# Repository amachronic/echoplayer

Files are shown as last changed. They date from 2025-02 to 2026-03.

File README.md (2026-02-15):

# Echo: Open Hardware Music Player

Echo is an open hardware platform for music players. The goal of
the project is to produce a high quality music player, based on
and designed with free software. It's primarily designed to run
[Rockbox](https://www.rockbox.org), a free music player firmware
with support for many codecs, and a wide array of features.

The PCB is designed with [KiCAD 9.0](https://www.kicad.org/),
and there is an unfinished 3D-printable case designed with
[build123d](https://github.com/gumyr/build123d).

All designs are available under the CERN-OHL-S v2 license.

The current version of the Echo player is called the Echo R1.
In the future, there could be new player models if there are
significant changes to the features or form factor, but old
models will always be supported.

## Echo R1

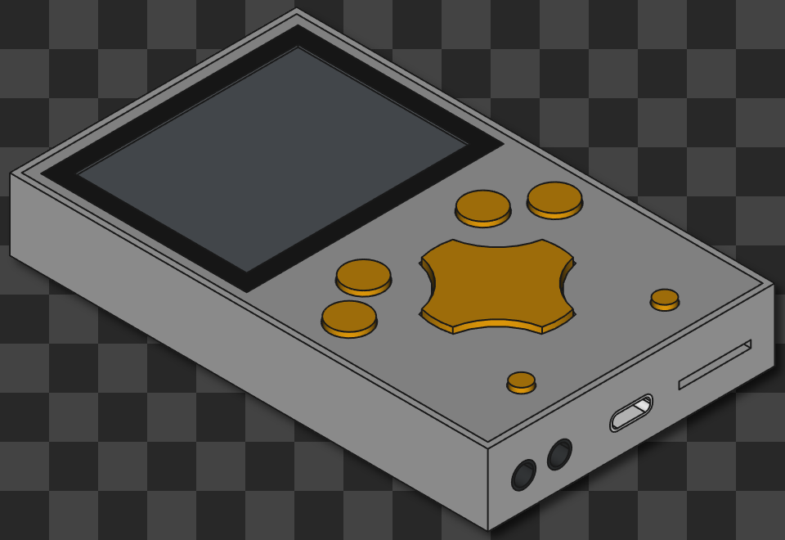
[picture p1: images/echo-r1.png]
3D render of Echo R1 case


- Size: 60x100x15mm (approx)
- Weight: TBD

The R1 has a 4-way D-pad and 6 multi-function buttons on the
faceplate, which can be used to quickly navigate your music
library and control playback. There are dedicated volume and
power buttons (not pictured), and a sliding hold switch near
the power button, which locks the buttons against accidental
presses when the player is in your pocket or bag.

There are two 3.5mm jacks, one for headphones, and one true
line-out port. The headphone jack supports recording from an
in-line microphone and playback control by an in-line remote.
Both jacks can be used simultaneously.

The removable memory card slot allows up to 2 TiB of storage
for your music and files. The USB-C port is used for charging
and file transfer, and supports high-speed USB 2.0.

The battery socket accepts the widely available BL-5C battery,
and the battery can easily be replaced without special tools
when it starts to wear out.

### Hardware specifications

| Component | Description |
| --- | --- |
| CPU | STM32H743 @ 480 MHz |
| Memory | 32 MiB SDRAM @ 120 MHz |
| Audio | TLV320AIC3104, up to 96 KHz, 0.707 V RMS  |
| Display | 18-bit, 320x240, 2.3 inch LCD |
| Storage | Expandable external memory card slot |
| USB | USB 2.0 @ 480 Mbps (High-speed) |
| Headphone out | Yes (3.5mm jack) |
| Line out | Yes (3.5mm jack) |
| Microphone | Can use wired headphone mic |
| RTC | Yes, with wake-up alarm function |
| Battery | Replaceable BL-5C battery (~1000 mAH) |

### Status

There are two versions of the R1 in the repo, the Rev1 and Rev2.

Rev1 is complete from an electrical standpoint but has a poorly
thought out mechanical design. A very early Rockbox port exists
but it is far from usable.

Rev2 is unfinished and focused mostly on solving the mechanical
issues with Rev1 properly. It is a near total redesign from an
electrical perspective, and uses a STM32H7R3 series CPU which
was selected mainly to simplify routing.

### Known issues (R1-Rev1 only)

- Reference designators in the schematics don't make much sense,
  there are gaps in the numbering and samed-valued components are
  not in contiguous ranges.
- Mounting screws are placed haphazardly and only two of them
  proved to be usable.
- The placement of the LCD and LCD connector is very awkward and
  makes it hard to diassemble the machine non-destructively.
- The lack of mounting holes also makes it difficult to connect
  front and back halves of the case securely.

## License

Unless otherwise noted, all files in this repository, including
this README, are available under the terms of the CERN-OHL-S
version 2 license, which should be found in the file `COPYING.txt`
alongside this README; or at <https://ohwr.org/cern_ohl_s_v2.txt>.

## Credits

Copyright (C) 2024-2025 Aidan MacDonald

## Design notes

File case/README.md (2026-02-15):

# Echo R1 Case

The Echo R1 case is designed with [build123d](https://github.com/gumyr/build123d),
a Python-based parametric BREP CAD package using the OpenCASCADE
geometry kernel. The case can be exported to STEP or STL files for
3D printing or to edit in other CAD applications.

## Installation

CAD models are produced by running the `echoplayer-case` script.
This needs to be installed first; the recommended way is to set
up a Python virtual environment (venv) and perform an editable
install, which allows you to modify and run the script in place.

This can be done from the shell / command line like this:

```
python3 -m venv .venv
source .venv/bin/activate
pip install -U pip
pip install -e .
```

## Exporting

To export STLs, run:

```
echoplayer-case --r1-rev1 --export out
```

You can also output STEP (or GLTF) files with the `--export-format` option:

```
echoplayer-case --r1-rev1 --export out --export-format stp
```

STEP is recommended if you want to make changes in another BREP
CAD package. STLs are meshes and only suitable for 3D printing.

The `--export DIR` option will write one file per unique part
to the output directory `DIR`. Some parts, like buttons, will
require multiple copies produced. At some point this will be
properly documented in BOM data for the player, but for now
you need to figure it out from looking at the render.

## Visualizing

If making edits to the code, you probably want to see what you are
doing to the model. There is built-in support for
[ocp_vscode](https://github.com/bernhard-42/vscode-ocp-cad-viewer),
which can be run either from VSCode or as a standalone server that
is accessed by a browser.

To start the standalone server:

```
python3 -m ocp_vscode
```

Navigate to `http://localhost:3939/viewer` in a browser and then
display the model with:

```
echoplayer-case --r1-rev1 --ocp-vscode
```

Passing the `--show-datums` option will include datum points and
planes in the visualization.

## Development

If you are going to be making any major changes to the Python code,
you should install development dependencies and run checks with `tox`.
Run the following command in a venv:

```
pip install -e .[dev]
```

Usage of `tox` is very simple:

```
tox r -e mypy   # type check
tox r -e ruff   # lint
tox r -e test   # test build of the case
tox p           # run all in parallel
```

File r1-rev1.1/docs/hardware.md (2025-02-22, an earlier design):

# Hardware notes

Usage notes for the hardware -- for further information consult the
KiCAD schematic and `pin_assign.ods` file.

## Fast/slow charging mode

To enable 450 mA charging, `~charging_enable` must be pulled to ground,
otherwise the charge is limited to 100 mA. This isn't strictly USB 2.0
compliant but provides an option to draw less current when plugging into
weak USB hosts (eg. a phone).

## Power-on circuit management

The power-on circuit controls the main 3.3V regulator enable pin and
thus is used to power on the STM32 MCU. There are 4 power-on signals
which are active high and OR'd through diodes:

* CPU power (`cpu_power_on` pin)
* RTC wakeup (`rtc_wakeup` pin)
* Power button
* VBUS input

In the normal case, the user will press and hold the power button to
power on the machine. Once the STM32 boots, the bootloader continues
to monitor the button, and if it stays pressed for a certain duration
it will assert the `cpu_power_on` request to keep the CPU powered on
once the power button is released.

The RTC wakeup case is much like the power button case, except that
the bootloader detects the RTC wakeup and boots the firmware with
no user input.

Providing USB power ensures the STM32 is powered even if there is no
software on it. This allows it to be flashed over SWD or USB-DFU.

To shut off the CPU, the firmware should drive `cpu_power_on` low and
wait for some time. It should then trigger a software reset in order
to re-enter the bootloader. If the bootloader is re-entered in this way
it should go into an idle mode to manage battery charging, etc, which
should appear as if the device is 'off' from the user perspective and
respond as expected to the power button / RTC alarm. If USB power is
lost, the bootloader should attempt to shut off the system again.

## Audio codec and jacks

There are two 3.5mm audio jacks driven by the TLV320AIC3104 codec:

- Headphone jack -- direct-coupled (capless) headphone amp output
- Line-out jack -- AC-coupled line output

Both jacks have insert detection and can be driven simultaneously.
The headphone jack supports recording from an inline microphone and
headset button detection following the Android 3.5mm accessory spec.
Both jacks are designed for the CTIA pinout and support 4-pin CTIA
and 3-pin plugs; 4-pin OMTP plugs may not work correctly.

## USB-DFU mode and SWD

The STM32 can be programmed using USB DFU mode by holding SELECT
while inserting a USB cable. This will enter the ST bootloader and
it should appear as a USB-DFU device.

The 6-pin SWD connector can be used to debug and program the STM32
using OpenOCD. This requires an SWD adapter such as the STLINK-V3SET.
The default configuration files for the STM32H743 and your adapter
should be sufficient, no special configuration is required.

Note that software breakpoints in GDB will not work correctly on
Cortex-M7 when the I-cache is enabled, due a bug in OpenOCD. To
work around this, you can use GDB's `hbreak` command to force the
use of hardware breakpoints or you can disable the I-cache.

## Board stackup and ordering information

The board is designed for JLCPCB's 6-layer JLC06101H-3313 stackup.
Trace widths have been selected to get 50-ohm impedance on single
ended signal traces and 90-ohm differential impedance on USB. Via
impedance wasn't taken into account as it shouldn't matter except
at much higher speeds.

For QFN exposed pads the grounding vias in the KiCAD footprint are
smaller than the min. size used on the rest of the board. It should
be fine to enlarge them to the standard via size if required but
JLCPCB seemed to accept them as-is.

| Parameter | Value |
| --- | --- |
| Layers | 6 |
| Thickness | 1.6mm |
| Material | FR-4 TG155 |
| Outer copper weight  | 1 oz |
| Inner copper weight  | 0.5 oz |
| Impedance controlled | Yes |
| Stackup | JLC06101H-3313 |
| Via covering | Epoxy filled & capped |
| Via pad/hole size | 0.45mm/0.3mm |

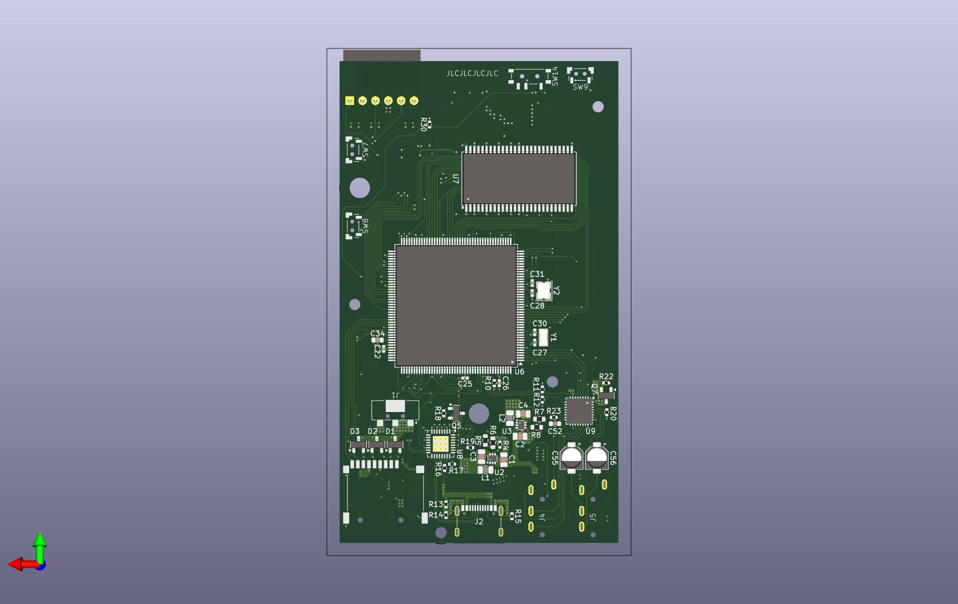
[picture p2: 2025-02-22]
images/echo-r1-back.jpg

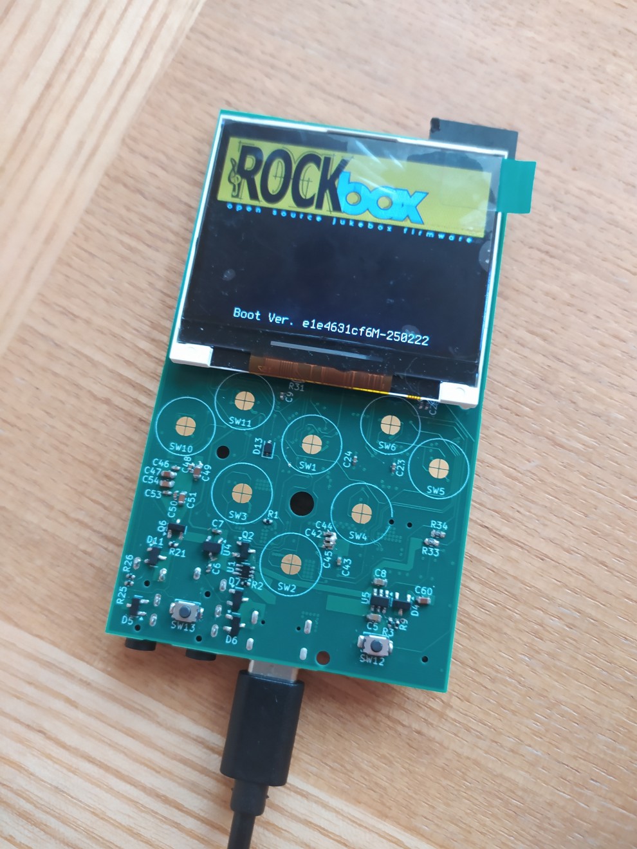
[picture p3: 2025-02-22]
images/echo-r1-rockbox.jpg

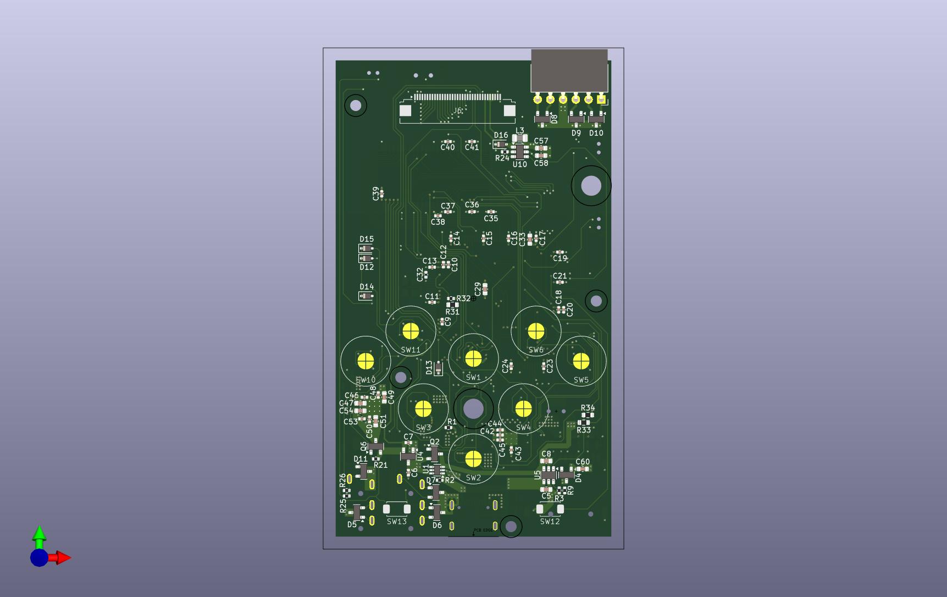
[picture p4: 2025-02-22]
images/echo-r1-front.jpg

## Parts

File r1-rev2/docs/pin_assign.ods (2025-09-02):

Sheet: README
PinAssign usage: | GPIO FUNCTION can be edited to mark a pin used as a GPIO, or give a name for an alternate function pin; use ‘-’ if the pin is not used/not named
 | PKGPIN and NAME are defined from the MCU datasheet – don’t edit these
 | ALT FUNCTION is populated automatically, don’t edit it
 | USED is populated automatically, it contains an ‘o’ if the pin is assigned to a GPIO or alternate function, ‘-’ if the pin is free
FunctionAssign usage: | Put an ‘x’ in the PIN NAME column if the alternate function is not used
 | Put the name of the GPIO (eg. PA3) in the PIN NAME column if the alternate function is assigned to that GPIO
 | Leave PIN NAME blank if undecided
 | FUNCTION is defined from the MCU datasheet – do not edit it
 | PKGPIN is populated automatically, don’t edit it
FunctionPinMux usage: | Used to view pins available for alternate functions, not used for editing. Use PinAssign/FunctionAssign to assign GPIOs or alternate functions.
_Data sheet: | contains a reverse mapping of pin name → pkgpin indices
 | also marks pins that are fixed function on the MCU so that those are always marked as ‘used’ on the PinAssign sheet

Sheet: PinAssign
PKGPIN | NAME | USED | ALT FUNCTION | GPIO FUNCTION | UnusedPinMark | x
A1 | VSS | o | - | - | UsedPinMark | o
A2 | PB8 | o | I2C1_SCL | codec_ctl.scl | NoPkgPinText | -
A3 | PB6 | o | USART1_TX | uart_tx
A4 | PB5 | - | - | -
A5 | PD7 | o | SDMMC2_CMD | sdmmc_int.cmd
A6 | BOOT0 | o | - | -
A7 | PM11 | o | OTG_FS_DP | -
A8 | PM9 | - | - | -
A9 | PM6 | o | OTG_HS_DP | -
A10 | VDD33USB | o | - | -
A11 | VDD50USB | o | - | -
A12 | VSS | o | - | -
B1 | VBAT | o | - | -
B2 | PC13 | o | RTC_OUT1 | rtc_wakeup
B3 | PE1 | - | - | -
B4 | PE0 | - | - | -
B5 | PB3 | o | SDMMC2_D2 | sdmmc_int.d2
B6 | PD5 | o | FMC_NCE | lcd.cs
B7 | PM12 | o | OTG_FS_DM | -
B8 | PM8 | o | OTG_HS_VBUS | -
B9 | PM5 | o | OTG_HS_DM | -
B10 | PM2 | - | - | -
B11 | PM3 | - | - | -
B12 | PD4 | - | - | -
C1 | PC14-OSC32_IN | o | OSC32_IN | -
C2 | PC15-OSC32_OUT | o | OSC32_OUT | -
C3 | PB9 | o | I2C1_SDA | codec_ctl.sda
C4 | PE2 | o | SAI1_MCLK_A | codec.mclk
C5 | PB4 | o | SDMMC2_D3 | sdmmc_int.d3
C6 | PD6 | o | SDMMC2_CK | sdmmc_int.clk
C7 | PM14 | o | OTG_FS_VBUS | -
C8 | DVDD | o | - | -
C9 | VSS | o | - | -
C10 | PM1 | - | - | -
C11 | PD2 | o | SDMMC1_CMD | sdmmc_ext.cmd
C12 | PC12 | o | SDMMC1_CK | sdmmc_ext.clk
D1 | PE5 | o | SAI1_SCK_A | codec.bclk
D2 | VSS | o | - | -
D3 | PE3 | o | SAI1_SD_B | codec.drec
D4 | PB7 | o | USART1_RX | uart_rx
D5 | VSS | o | - | -
D6 | VDD | o | - | -
D7 | VSS | o | - | -
D8 | VSSUSB | o | - | -
D9 | VDD | o | - | -
D10 | PD3 | o | FMC_NWAIT | -
D11 | PC10 | o | SDMMC1_D2 | sdmmc_ext.d2
D12 | PA15 | - | - | -
E1 | VSSSMPS | o | - | -
E2 | PE6 | o | SAI1_SD_A | codec.dplay
E3 | PE4 | o | SAI1_FS_A | codec.wclk
E4 | VDD | o | - | -
E5 | VCAP4 | o | - | -
E6 | PM13 | - | - | -
E7 | VSS | o | - | -
E8 | PM0 | - | - | -
E9 | PC11 | o | SDMMC1_D3 | sdmmc_ext.d3
E10 | PA14 | o | JTCK-SWCLK | -
E11 | PA12 | o | FMC_D0 | lcd.d0
E12 | PA13 | o | JTMS-SWDIO | -
F1 | VLXSMPS | o | - | -
F2 | VDDSMPS | o | - | -
F3 | VFBSMPS | o | - | -
F4 | NRST | o | - | -
F5 | VSS | o | - | -
F6 | VDDLDO | o | - | -
F7 | VDDLDO | o | - | -
F8 | VCAP3 | o | - | -
F9 | VDD | o | - | -
F10 | PA8 | o | FMC_D4 | lcd.d4
F11 | PA10 | o | FMC_D2 | lcd.d2
F12 | PA11 | o | FMC_D1 | lcd.d1
G1 | VSS | o | - | -
G2 | PH0-OSC_IN | o | OSC_IN | -
G3 | PC0 | - | - | -
G4 | VDD | o | - | -
G5 | PC1 | - | - | -
G6 | VDDLDO | o | - | -
G7 | VDDLDO | o | - | -
G8 | VSS | o | - | -
G9 | PC7 | - | - | -
G10 | PC9 | o | SDMMC1_D1 | sdmmc_ext.d1
G11 | PC8 | o | SDMMC1_D0 | sdmmc_ext.d0
G12 | PA9 | o | FMC_D3 | lcd.d3
H1 | PH1-OSC_OUT | o | OSC_OUT | -
H2 | PC3 | o | ADC12_INN12 | hp_micbutton-
H3 | VSSA | o | - | -
H4 | VSS | o | - | -
H5 | VREFM | o | - | -
H6 | VCAP1 | o | - | -
H7 | VSS | o | - | -
H8 | VCAP2 | o | - | -
H9 | PB14 | o | SDMMC2_D0 | sdmmc_int.d0
H10 | PB12 | - | - | -
H11 | PD14 | o | LPTIM2_CH1 | cpu_power_on
H12 | PC6 | - | - | -
J1 | PC2 | o | ADC12_INP12 | hp_micbutton+
J2 | PA1 | o | FMC_D6 | lcd.d6
J3 | VDDA | o | - | -
J4 | PA5 | - | - | -
J5 | VDD | o | - | -
J6 | PO1 | - | - | -
J7 | PO0 | o | XSPIM_P1_NCS1 | xspi.cs
J8 | PD8 | - | - | -
J9 | VDD | o | - | -
J10 | PB10 | - | - | -
J11 | PB13 | - | - | -
J12 | PB15 | o | SDMMC2_D1 | sdmmc_int.d1
K1 | PA0 | o | FMC_D7 | lcd.d7
K2 | PA3 | - | - | -
K3 | VREFP | o | - | -
K4 | PA7 | o | ADC12_INP7 | adc_vbat
K5 | VDDXSPI1 | o | - | -
K6 | VSS | o | - | -
K7 | VDDXSPI1 | o | - | -
K8 | VSS | o | - | -
K9 | VDDXSPI1 | o | - | -
K10 | VSS | o | - | -
K11 | PD12 | - | - | -
K12 | PB11 | - | - | -
L1 | PA2 | o | FMC_D5 | lcd.d5
L2 | PA4 | - | - | -
L3 | PC4 | o | FMC_A19 | lcd.dcx
L4 | PB0 | - | - | -
L5 | PB2 | o | FMC_NWE | lcd.wrx
L6 | PP2 | o | XSPIM_P1_IO2 | xspi.d2
L7 | PO5 | o | XSPIM_P1_NCLK | xspi.clk-
L8 | PP0 | o | XSPIM_P1_IO0 | xspi.d0
L9 | PO2 | o | XSPIM_P1_DQS0 | xspi.dqs0
L10 | PP1 | o | XSPIM_P1_IO1 | xspi.d1
L11 | PD11 | - | - | -
L12 | PD13 | o | LPTIM1_CH1 | backlight_pwm
M1 | VSS | o | - | -
M2 | PA6 | - | - | -
M3 | PC5 | o | ADC12_INP8 | adc_vbus
M4 | PB1 | o | FMC_NOE | lcd.rdx
M5 | PP4 | o | XSPIM_P1_IO4 | xspi.d4
M6 | PP3 | o | XSPIM_P1_IO3 | xspi.d3
M7 | PO4 | o | XSPIM_P1_CLK | xspi.clk+
M8 | PP5 | o | XSPIM_P1_IO5 | xspi.d5
M9 | PP6 | o | XSPIM_P1_IO6 | xspi.d6
M10 | PP7 | o | XSPIM_P1_IO7 | xspi.d7
M11 | PD10 | - | - | -
M12 | VSS | o | - | -
 | TOTAL PINS USED | 115
 | TOTAL PINS FREE | 29

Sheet: FunctionAssign
PKGPIN | FUNCTION | PIN NAME
L8 | XSPIM_P1_IO0 | PP0
L10 | XSPIM_P1_IO1 | PP1
L6 | XSPIM_P1_IO2 | PP2
M6 | XSPIM_P1_IO3 | PP3
M5 | XSPIM_P1_IO4 | PP4
M8 | XSPIM_P1_IO5 | PP5
M9 | XSPIM_P1_IO6 | PP6
M10 | XSPIM_P1_IO7 | PP7
L9 | XSPIM_P1_DQS0 | PO2
M7 | XSPIM_P1_CLK | PO4
L7 | XSPIM_P1_NCLK | PO5
J7 | XSPIM_P1_NCS1 | PO0
- | FMC_A0 | x
- | FMC_A1 | x
- | FMC_A2 | x
- | FMC_A3 | x
- | FMC_A4 | x
- | FMC_A5 | x
- | FMC_A6 | x
- | FMC_A7 | x
- | FMC_A16 | x
- | FMC_A17 | x
- | FMC_A18 | x
L3 | FMC_A19 | PC4
- | FMC_A20 | x
- | FMC_A21 | x
E11 | FMC_D0 | PA12
F12 | FMC_D1 | PA11
F11 | FMC_D2 | PA10
G12 | FMC_D3 | PA9
F10 | FMC_D4 | PA8
L1 | FMC_D5 | PA2
J2 | FMC_D6 | PA1
K1 | FMC_D7 | PA0
- | FMC_D8 | x
- | FMC_D9 | x
- | FMC_D10 | x
- | FMC_D11 | x
- | FMC_D12 | x
- | FMC_D13 | x
- | FMC_D14 | x
- | FMC_D15 | x
M4 | FMC_NOE | PB1
L5 | FMC_NWE | PB2
D10 | FMC_NWAIT | PD3
B6 | FMC_NCE | PD5
- | FMC_NE1 | x
C12 | SDMMC1_CK | PC12
C11 | SDMMC1_CMD | PD2
G11 | SDMMC1_D0 | PC8
G10 | SDMMC1_D1 | PC9
D11 | SDMMC1_D2 | PC10
E9 | SDMMC1_D3 | PC11
C6 | SDMMC2_CK | PD6
A5 | SDMMC2_CMD | PD7
H9 | SDMMC2_D0 | PB14
J12 | SDMMC2_D1 | PB15
B5 | SDMMC2_D2 | PB3
C5 | SDMMC2_D3 | PB4
B9 | OTG_HS_DM | PM5
A9 | OTG_HS_DP | PM6
- | OTG_HS_ID | x
- | OTG_HS_SOF | x
B8 | OTG_HS_VBUS | PM8
A7 | OTG_FS_DP | PM11
B7 | OTG_FS_DM | PM12
C7 | OTG_FS_VBUS | PM14
E3 | SAI1_FS_A | PE4
- | SAI1_FS_B | x
C4 | SAI1_MCLK_A | PE2
- | SAI1_MCLK_B | x
D1 | SAI1_SCK_A | PE5
- | SAI1_SCK_B | x
E2 | SAI1_SD_A | PE6
D3 | SAI1_SD_B | PE3
- | SAI2_FS_A | x
- | SAI2_FS_B | x
- | SAI2_MCLK_A | x
- | SAI2_MCLK_B | x
- | SAI2_SCK_A | x
- | SAI2_SCK_B | x
- | SAI2_SD_A | x
- | SAI2_SD_B | x
A2 | I2C1_SCL | PB8
C3 | I2C1_SDA | PB9
- | I2C2_SCL | x
- | I2C2_SDA | x
- | I2C3_SCL | x
- | I2C3_SDA | x
L12 | LPTIM1_CH1 | PD13
- | LPTIM1_CH2 | x
H11 | LPTIM2_CH1 | PD14
- | LPTIM2_CH2 | x
- | LPTIM3_CH1 | x
- | LPTIM3_CH2 | x
K4 | ADC12_INP7 | PA7
M3 | ADC12_INP8 | PC5
J1 | ADC12_INP12 | PC2
H2 | ADC12_INN12 | PC3
B2 | RTC_OUT1 | PC13
A3 | USART1_TX | PB6
D4 | USART1_RX | PB7
E10 | JTCK-SWCLK | PA14
E12 | JTMS-SWDIO | PA13
C1 | OSC32_IN | PC14-OSC32_IN
C2 | OSC32_OUT | PC15-OSC32_OUT
G2 | OSC_IN | PH0-OSC_IN
H1 | OSC_OUT | PH1-OSC_OUT

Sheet: FunctionPinMux
FUNCTION | PINS
XSPIM_P1_IO0 | PP0
XSPIM_P1_IO1 | PP1
XSPIM_P1_IO2 | PP2
XSPIM_P1_IO3 | PP3
XSPIM_P1_IO4 | PP4
XSPIM_P1_IO5 | PP5
XSPIM_P1_IO6 | PP6
XSPIM_P1_IO7 | PP7
XSPIM_P1_DQS0 | PO2
XSPIM_P1_CLK | PO4
XSPIM_P1_NCLK | PO5
XSPIM_P1_NCS1 | PO0
FMC_A0 | PC1
FMC_A1 | PC2
FMC_A2 | PC3
FMC_A3 | PC4
FMC_A4 | PE7
FMC_A5 | PC5
FMC_A6 | PD0
FMC_A7 | PD1
FMC_A16 | PC1
FMC_A17 | PC2
FMC_A18 | PC3
FMC_A19 | PC4
FMC_A20 | PB15
FMC_A21 | PC5
FMC_D0 | PA12
FMC_D1 | PA11
FMC_D2 | PA10
FMC_D3 | PA9
FMC_D4 | PA8
FMC_D5 | PA2
FMC_D6 | PA1
FMC_D7 | PA0
FMC_D8 | PB13 | PD7
FMC_D9 | PB12 | PE0 | PB8
FMC_D10 | PB11 | PE1
FMC_D11 | PB10 | PE2
FMC_D12 | PB5 | PE3
FMC_D13 | PB4 | PE4
FMC_D14 | PB3 | PE5
FMC_D15 | PA15 | PE6
FMC_NOE | PB1 | PA5
FMC_NWE | PB2
FMC_NWAIT | PD3
FMC_NCE | PD5
FMC_NE1 | PD12 | PB14
SDMMC1_CK | PC12
SDMMC1_CMD | PD2
SDMMC1_D0 | PB13 | PC8
SDMMC1_D1 | PC9
SDMMC1_D2 | PC10
SDMMC1_D3 | PC11
SDMMC2_CK | PC1 | PD6
SDMMC2_CMD | PA0 | PD7
SDMMC2_D0 | PB14
SDMMC2_D1 | PB15
SDMMC2_D2 | PB3
SDMMC2_D3 | PB4
OTG_HS_DM | PM5
OTG_HS_DP | PM6
OTG_HS_ID | PM9
OTG_HS_SOF | PA4
OTG_HS_VBUS | PM8
OTG_FS_DP | PM11
OTG_FS_DM | PM12
OTG_FS_VBUS | PM14
SAI1_FS_A | PE4
SAI1_FS_B | PF9
SAI1_MCLK_A | PE2
SAI1_MCLK_B | PF7
SAI1_SCK_A | PE5 | PD6
SAI1_SCK_B | PF8
SAI1_SD_A | PE6 | PC1 | PB2
SAI1_SD_B | PE3 | PF6
SAI2_FS_A | PD12
SAI2_FS_B | PC0 | PG9 | PA12 | PE13
SAI2_MCLK_A | PE0
SAI2_MCLK_B | PE6 | PA1 | PE14
SAI2_SCK_A | PD13
SAI2_SCK_B | PA2 | PE12
SAI2_SD_A | PD11
SAI2_SD_B | PF11 | PE7 | PG10 | PE11
I2C1_SCL | PB6 | PB8
I2C1_SDA | PB9 | PB7
I2C2_SCL | PB10 | PF1
I2C2_SDA | PB11 | PF0
I2C3_SCL | PA8
I2C3_SDA | PC9 | PA9
LPTIM1_CH1 | PD13
LPTIM1_CH2 | PD14
LPTIM2_CH1 | PB13 | PD14
LPTIM2_CH2 | PB14 | PE1
LPTIM3_CH1 | PA3
LPTIM3_CH2 | PA4
ADC12_INP7 | PA7
ADC12_INP8 | PC5
ADC12_INP12 | PC2
ADC12_INN12 | PC3
RTC_OUT1 | PC13
USART1_TX | PB14 | PA9 | PB6
USART1_RX | PB15 | PA10 | PB7
JTCK-SWCLK | PA14
JTMS-SWDIO | PA13
OSC32_IN | PC14-OSC32_IN
OSC32_OUT | PC15-OSC32_OUT
OSC_IN | PH0-OSC_IN
OSC_OUT | PH1-OSC_OUT

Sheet: _Data
NAME | PKGPIN | FIXED FUNCTION
VSS | A1 | TRUE
PB8 | A2 | FALSE
PB6 | A3 | FALSE
PB5 | A4 | FALSE
PD7 | A5 | FALSE
BOOT0 | A6 | TRUE
PM11 | A7 | FALSE
PM9 | A8 | FALSE
PM6 | A9 | FALSE
VDD33USB | A10 | TRUE
VDD50USB | A11 | TRUE
VSS | A12 | TRUE
VBAT | B1 | TRUE
PC13 | B2 | FALSE
PE1 | B3 | FALSE
PE0 | B4 | FALSE
PB3 | B5 | FALSE
PD5 | B6 | FALSE
PM12 | B7 | FALSE
PM8 | B8 | FALSE
PM5 | B9 | FALSE
PM2 | B10 | FALSE
PM3 | B11 | FALSE
PD4 | B12 | FALSE
PC14-OSC32_IN | C1 | FALSE
PC15-OSC32_OUT | C2 | FALSE
PB9 | C3 | FALSE
PE2 | C4 | FALSE
PB4 | C5 | FALSE
PD6 | C6 | FALSE
PM14 | C7 | FALSE
DVDD | C8 | TRUE
VSS | C9 | TRUE
PM1 | C10 | FALSE
PD2 | C11 | FALSE
PC12 | C12 | FALSE
PE5 | D1 | FALSE
VSS | D2 | TRUE
PE3 | D3 | FALSE
PB7 | D4 | FALSE
VSS | D5 | TRUE
VDD | D6 | TRUE
VSS | D7 | TRUE
VSSUSB | D8 | TRUE
VDD | D9 | TRUE
PD3 | D10 | FALSE
PC10 | D11 | FALSE
PA15 | D12 | FALSE
VSSSMPS | E1 | TRUE
PE6 | E2 | FALSE
PE4 | E3 | FALSE
VDD | E4 | TRUE
VCAP4 | E5 | TRUE
PM13 | E6 | FALSE
VSS | E7 | TRUE
PM0 | E8 | FALSE
PC11 | E9 | FALSE
PA14 | E10 | FALSE
PA12 | E11 | FALSE
PA13 | E12 | FALSE
VLXSMPS | F1 | TRUE
VDDSMPS | F2 | TRUE
VFBSMPS | F3 | TRUE
NRST | F4 | TRUE
VSS | F5 | TRUE
VDDLDO | F6 | TRUE
VDDLDO | F7 | TRUE
VCAP3 | F8 | TRUE
VDD | F9 | TRUE
PA8 | F10 | FALSE
PA10 | F11 | FALSE
PA11 | F12 | FALSE
VSS | G1 | TRUE
PH0-OSC_IN | G2 | FALSE
PC0 | G3 | FALSE
VDD | G4 | TRUE
PC1 | G5 | FALSE
VDDLDO | G6 | TRUE
VDDLDO | G7 | TRUE
VSS | G8 | TRUE
PC7 | G9 | FALSE
PC9 | G10 | FALSE
PC8 | G11 | FALSE
PA9 | G12 | FALSE
PH1-OSC_OUT | H1 | FALSE
PC3 | H2 | FALSE
VSSA | H3 | TRUE
VSS | H4 | TRUE
VREFM | H5 | TRUE
VCAP1 | H6 | TRUE
VSS | H7 | TRUE
VCAP2 | H8 | TRUE
PB14 | H9 | FALSE
PB12 | H10 | FALSE
PD14 | H11 | FALSE
PC6 | H12 | FALSE
PC2 | J1 | FALSE
PA1 | J2 | FALSE
VDDA | J3 | TRUE
PA5 | J4 | FALSE
VDD | J5 | TRUE
PO1 | J6 | FALSE
PO0 | J7 | FALSE
PD8 | J8 | FALSE
VDD | J9 | TRUE
PB10 | J10 | FALSE
PB13 | J11 | FALSE
PB15 | J12 | FALSE
PA0 | K1 | FALSE
PA3 | K2 | FALSE
VREFP | K3 | TRUE
PA7 | K4 | FALSE
VDDXSPI1 | K5 | TRUE
VSS | K6 | TRUE
VDDXSPI1 | K7 | TRUE
VSS | K8 | TRUE
VDDXSPI1 | K9 | TRUE
VSS | K10 | TRUE
PD12 | K11 | FALSE
PB11 | K12 | FALSE
PA2 | L1 | FALSE
PA4 | L2 | FALSE
PC4 | L3 | FALSE
PB0 | L4 | FALSE
PB2 | L5 | FALSE
PP2 | L6 | FALSE
PO5 | L7 | FALSE
PP0 | L8 | FALSE
PO2 | L9 | FALSE
PP1 | L10 | FALSE
PD11 | L11 | FALSE
PD13 | L12 | FALSE
VSS | M1 | TRUE
PA6 | M2 | FALSE
PC5 | M3 | FALSE
PB1 | M4 | FALSE
PP4 | M5 | FALSE
PP3 | M6 | FALSE
PO4 | M7 | FALSE
PP5 | M8 | FALSE
PP6 | M9 | FALSE
PP7 | M10 | FALSE
PD10 | M11 | FALSE
VSS | M12 | TRUE

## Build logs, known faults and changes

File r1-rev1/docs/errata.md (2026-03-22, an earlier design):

# Errata list for Echo-R1-Rev1 PCB

## 1. USB3320C ID pin incorrectly connected

As per the USB3320C datasheet's description of the ID pin:

> For applications not using ID this pin can be connected
> to VDD33. For an A-Device ID is grounded. For a B-Device
> ID is floated.

However, the ID pin is connected to ground, which causes
the DWC2 USB core to go into host mode unless the FDMOD
bit is set by software to force the core to device mode.

Github issue: #9

## 2. HP/LO jacks have incorrect pinout

Due to a mistake in the pin assignment for the 3.5mm jack
footprint, both jacks are incorrectly wired and will not
work with standard headphones. To get normal audio output
a custom 4-pin TRRS male-to-female adapter is needed.

The schematic shows the actual connectivity with notes on
how to construct a custom adapter.

Github issue: #12

## 3. ESD diode capacitance exceeds SDMMC bus limit

Diodes D1-D4 should be left unpopulated since they add
too much capacitance and cause the SDMMC bus to fail at
higher speeds.

Github issue: #27

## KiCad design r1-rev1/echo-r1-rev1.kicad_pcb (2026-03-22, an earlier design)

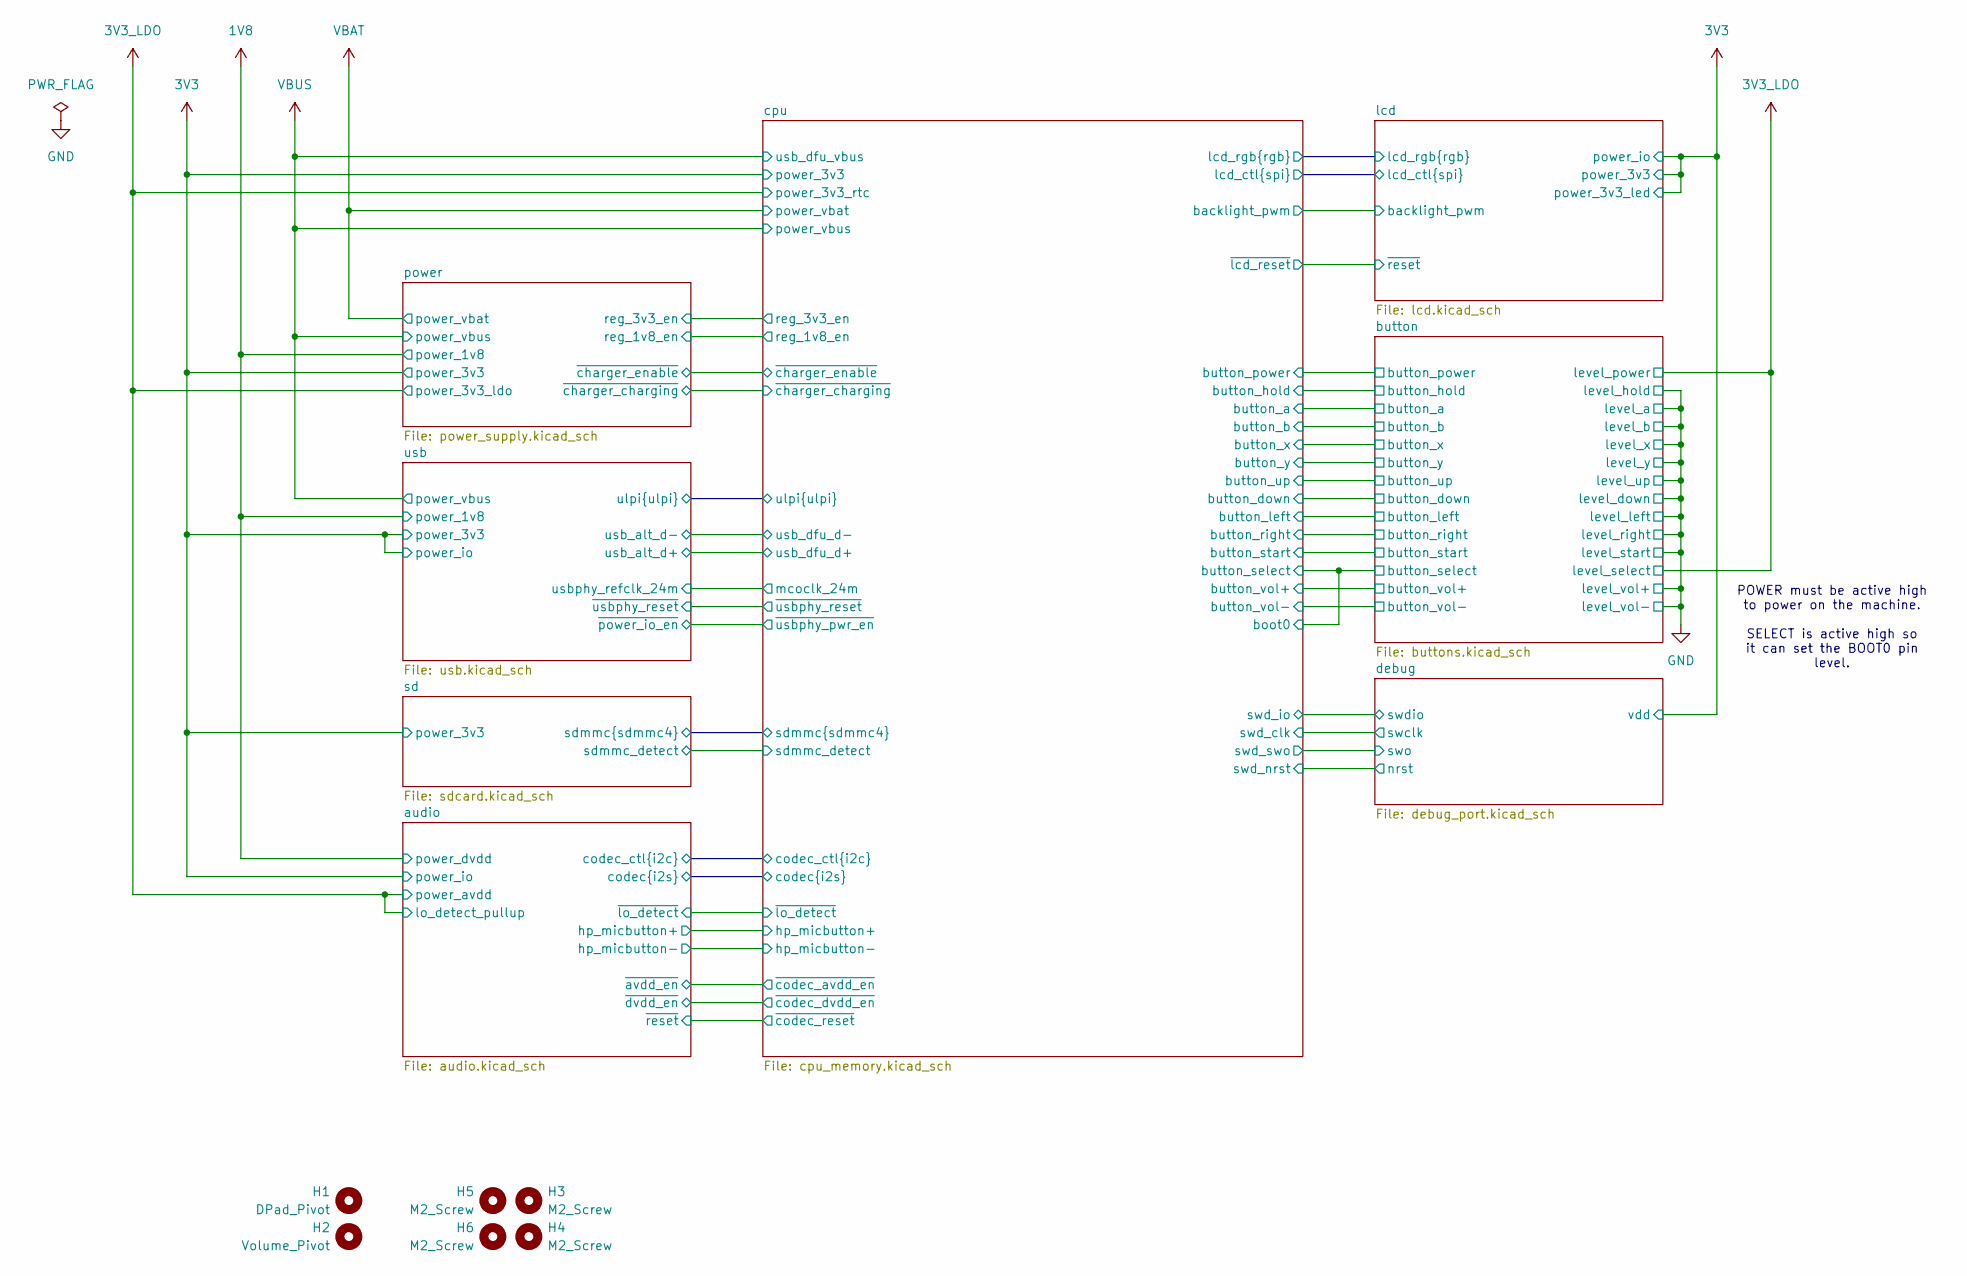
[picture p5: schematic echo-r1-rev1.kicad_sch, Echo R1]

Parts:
H1: DPad_Pivot; MountingHole_4mm
H2: Volume_Pivot; MountingHole_4mm
H3, H4, H5, H6: M2_Screw; MountingHole_2.2mm_M2

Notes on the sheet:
POWER must be active high to power on the machine. SELECT is active high so it can set the BOOT0 pin level.

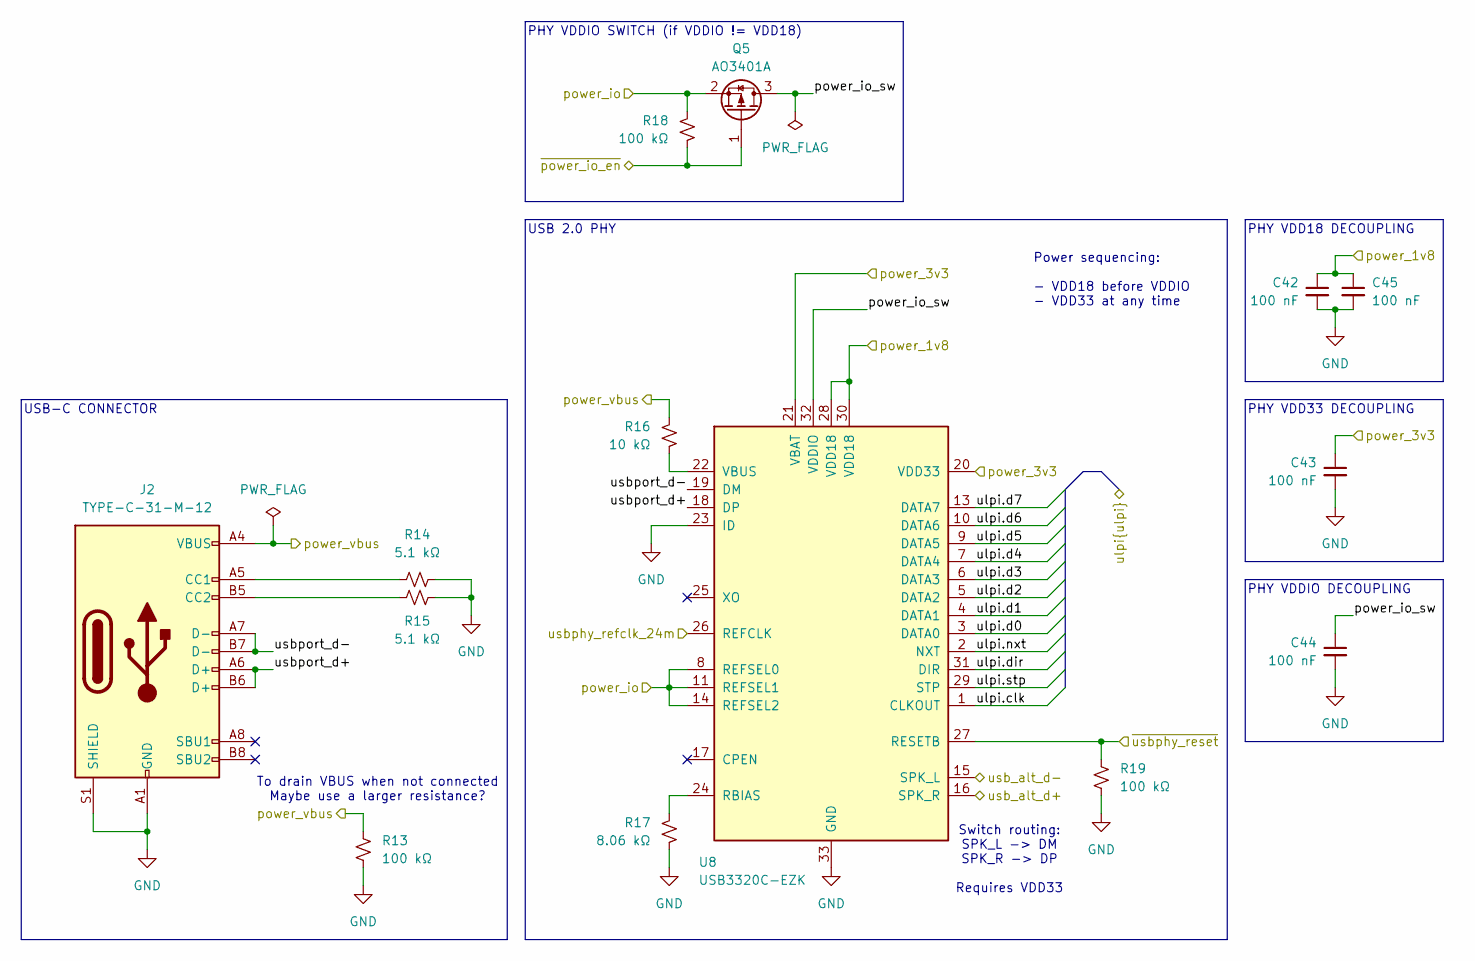
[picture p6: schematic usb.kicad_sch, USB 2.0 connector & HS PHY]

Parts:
C42, C43, C44, C45: 100 nF; C_0402_1005Metric; LCSC# C77020
J2: TYPE-C-31-M-12; USB_C-Hroparts-TYPE-C-31-M-12; LCSC# C165948
Q5: AO3401A; SOT-23; LCSC# C347476
R13, R18, R19: 100 kΩ; R_0402_1005Metric; LCSC# C60491
R14, R15: 5.1 kΩ; R_0402_1005Metric; LCSC# C25905
R16: 10 kΩ; R_0402_1005Metric; LCSC# C60490
R17: 8.06 kΩ; R_0402_1005Metric; LCSC# C276278
U8: USB3320C-EZK; QFN-32-1EP_5x5mm_P0.5mm_EP3.1x3.1mm_ThermalVias; LCSC# C132156

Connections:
1V8: C42.1, C45.1, U8.28 (VDD18), U8.30 (VDD18); also elsewhere on the board
3V3: C43.1, Q5.2 (S), R18.1, U8.8 (REFSEL0), U8.11 (REFSEL1), U8.14 (REFSEL2), U8.20 (VDD33), U8.21 (VBAT); also elsewhere on the board
/cpu/mcoclk_24m: U8.26 (REFCLK); also elsewhere on the board
/cpu/ulpi.clk: U8.1 (CLKOUT); also elsewhere on the board
/cpu/ulpi.d0: U8.3 (DATA0); also elsewhere on the board
/cpu/ulpi.d1: U8.4 (DATA1); also elsewhere on the board
/cpu/ulpi.d2: U8.5 (DATA2); also elsewhere on the board
/cpu/ulpi.d3: U8.6 (DATA3); also elsewhere on the board
/cpu/ulpi.d4: U8.7 (DATA4); also elsewhere on the board
/cpu/ulpi.d5: U8.9 (DATA5); also elsewhere on the board
/cpu/ulpi.d6: U8.10 (DATA6); also elsewhere on the board
/cpu/ulpi.d7: U8.13 (DATA7); also elsewhere on the board
/cpu/ulpi.dir: U8.31 (DIR); also elsewhere on the board
/cpu/ulpi.nxt: U8.2 (NXT); also elsewhere on the board
/cpu/ulpi.stp: U8.29 (STP); also elsewhere on the board
/cpu/usb_dfu_d+: U8.16 (SPK_R); also elsewhere on the board
/cpu/usb_dfu_d-: U8.15 (SPK_L); also elsewhere on the board
/cpu/~usbphy_pwr_en: Q5.1 (G), R18.2; also elsewhere on the board
/cpu/~usbphy_reset: R19.1, U8.27 (RESETB); also elsewhere on the board
/usb/power_io_sw: C44.1, Q5.3 (D), U8.32 (VDDIO)
/usb/usbport_d+: J2.A6 (D+), J2.B6 (D+), U8.18 (DP)
/usb/usbport_d-: J2.A7 (D-), J2.B7 (D-), U8.19 (DM)
GND: C42.2, C43.2, C44.2, C45.2, J2.A1 (GND), J2.A12 (GND), J2.B1 (GND), J2.B12 (GND), J2.S1 (SHIELD), R13.2, R14.2, R15.2, R17.1, R19.2, U8.23 (ID), U8.33 (GND); also elsewhere on the board
unnamed: J2.A5 (CC1), R14.1
unnamed: J2.B5 (CC2), R15.1
unnamed: R17.2, U8.24 (RBIAS)
unnamed: R16.1, U8.22 (VBUS)
VBUS: J2.A4 (VBUS), J2.A9 (VBUS), J2.B4 (VBUS), J2.B9 (VBUS), R13.1, R16.2; also elsewhere on the board

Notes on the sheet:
USB 2.0 PHY
Switch routing: SPK_L -> DM SPK_R -> DP Requires VDD33
To drain VBUS when not connected Maybe use a larger resistance?
USB-C CONNECTOR
PHY VDDIO DECOUPLING
PHY VDD33 DECOUPLING
PHY VDD18 DECOUPLING
Power sequencing: - VDD18 before VDDIO - VDD33 at any time
PHY VDDIO SWITCH (if VDDIO != VDD18)

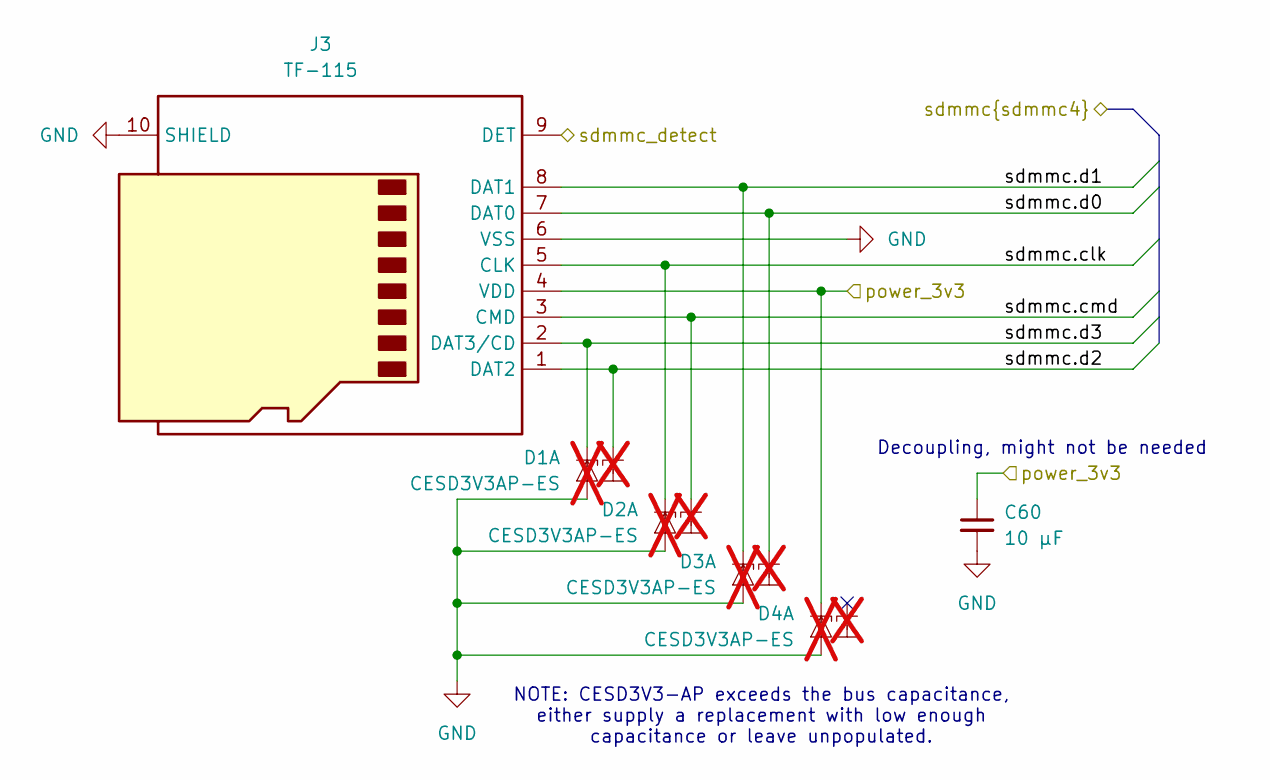
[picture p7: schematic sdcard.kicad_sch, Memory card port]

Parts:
C60: 10 µF; C_0603_1608Metric; LCSC# C91606
D1, D2, D3, D4: CESD3V3AP-ES; SOT-23; LCSC# C5199223; not fitted
J3: TF-115; microSD_XUNPU_TF-115; LCSC# C720505

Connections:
3V3: C60.1, D4.1 (K1), J3.4 (VDD); also elsewhere on the board
/cpu/sdmmc.clk: D2.1 (K1), J3.5 (CLK); also elsewhere on the board
/cpu/sdmmc.cmd: D2.2 (K2), J3.3 (CMD); also elsewhere on the board
/cpu/sdmmc.d0: D3.2 (K2), J3.7 (DAT0); also elsewhere on the board
/cpu/sdmmc.d1: D3.1 (K1), J3.8 (DAT1); also elsewhere on the board
/cpu/sdmmc.d2: D1.2 (K2), J3.1 (DAT2); also elsewhere on the board
/cpu/sdmmc.d3: D1.1 (K1), J3.2 (DAT3/CD); also elsewhere on the board
/cpu/sdmmc_detect: J3.9 (DET); also elsewhere on the board
GND: C60.2, D1.3 (A), D2.3 (A), D3.3 (A), D4.3 (A), J3.6 (VSS), J3.10 (SHIELD); also elsewhere on the board

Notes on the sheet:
NOTE: CESD3V3-AP exceeds the bus capacitance, either supply a replacement with low enough capacitance or leave unpopulated.
Decoupling, might not be needed

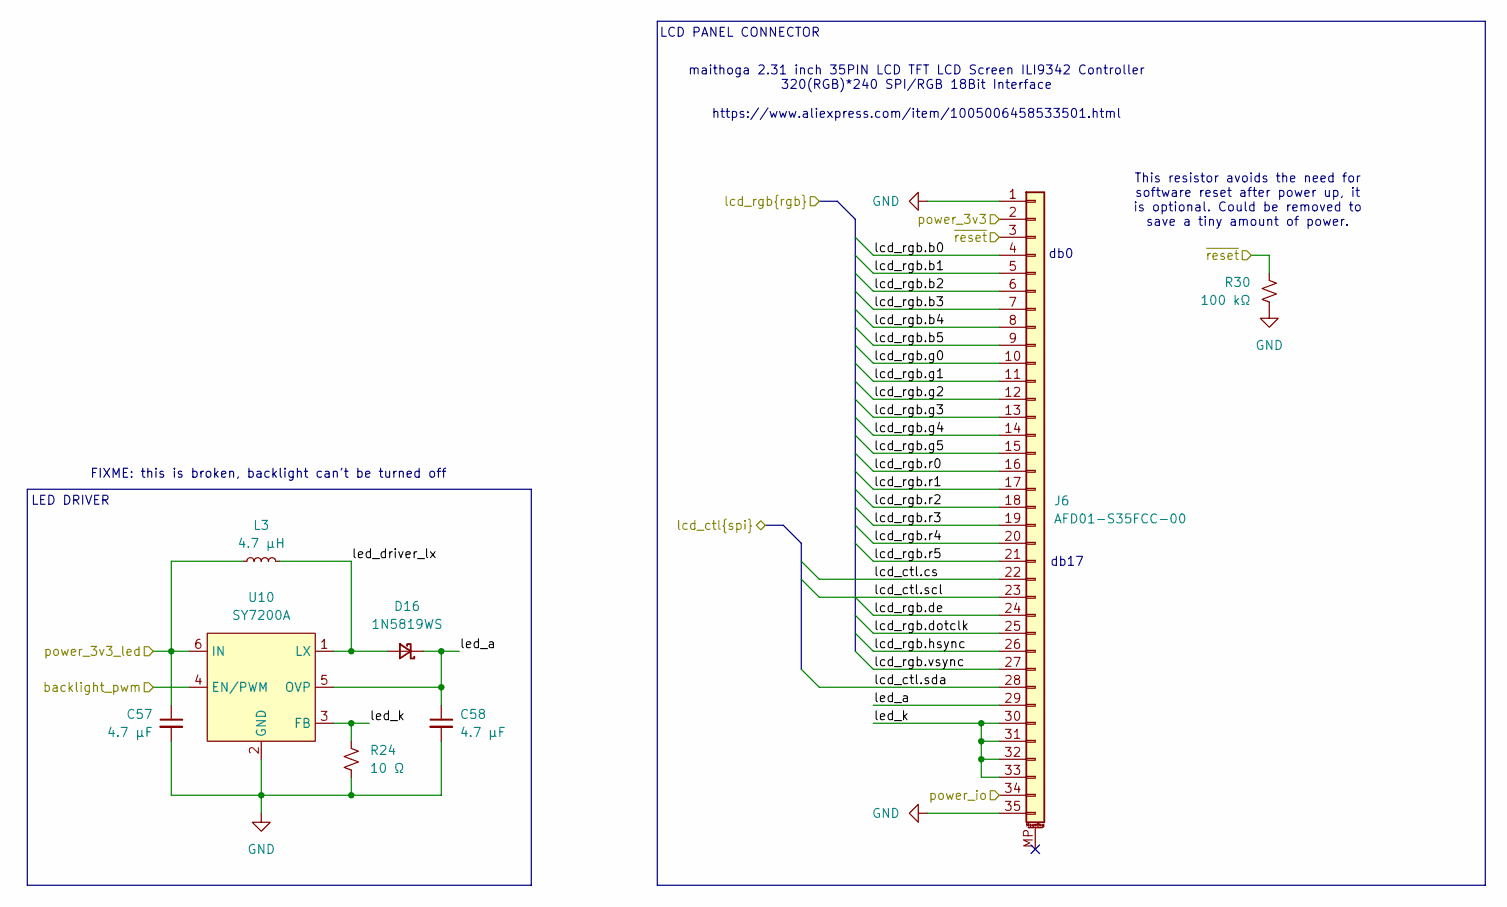
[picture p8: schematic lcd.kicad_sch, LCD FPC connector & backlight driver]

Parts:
C57, C58: 4.7 µF; C_0603_1608Metric; LCSC# C69335
D16: 1N5819WS; D_SOD-323; LCSC# C191023
J6: AFD01-S35FCC-00; Conn_Jushuo_AFD01-S35FCC-00_RTL; LCSC# C18198555
L3: 4.7 µH; L_0806_2016Metric; LCSC# C86094
R24: 10 Ω; R_0402_1005Metric; LCSC# C25077
R30: 100 kΩ; R_0402_1005Metric; LCSC# C60491
U10: SY7200A; SOT-23-6; LCSC# C107309

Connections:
3V3: C57.1, J6.2, J6.34, L3.1, U10.6 (IN); also elsewhere on the board
/cpu/backlight_pwm: U10.4 (EN/PWM); also elsewhere on the board
/cpu/lcd_ctl.cs: J6.22; also elsewhere on the board
/cpu/lcd_ctl.scl: J6.23; also elsewhere on the board
/cpu/lcd_ctl.sda: J6.28; also elsewhere on the board
/cpu/lcd_rgb.b0: J6.4; also elsewhere on the board
/cpu/lcd_rgb.b1: J6.5; also elsewhere on the board
/cpu/lcd_rgb.b2: J6.6; also elsewhere on the board
/cpu/lcd_rgb.b3: J6.7; also elsewhere on the board
/cpu/lcd_rgb.b4: J6.8; also elsewhere on the board
/cpu/lcd_rgb.b5: J6.9; also elsewhere on the board
/cpu/lcd_rgb.de: J6.24; also elsewhere on the board
/cpu/lcd_rgb.dotclk: J6.25; also elsewhere on the board
/cpu/lcd_rgb.g0: J6.10; also elsewhere on the board
/cpu/lcd_rgb.g1: J6.11; also elsewhere on the board
/cpu/lcd_rgb.g2: J6.12; also elsewhere on the board
/cpu/lcd_rgb.g3: J6.13; also elsewhere on the board
/cpu/lcd_rgb.g4: J6.14; also elsewhere on the board
/cpu/lcd_rgb.g5: J6.15; also elsewhere on the board
/cpu/lcd_rgb.hsync: J6.26; also elsewhere on the board
/cpu/lcd_rgb.r0: J6.16; also elsewhere on the board
/cpu/lcd_rgb.r1: J6.17; also elsewhere on the board
/cpu/lcd_rgb.r2: J6.18; also elsewhere on the board
/cpu/lcd_rgb.r3: J6.19; also elsewhere on the board
/cpu/lcd_rgb.r4: J6.20; also elsewhere on the board
/cpu/lcd_rgb.r5: J6.21; also elsewhere on the board
/cpu/lcd_rgb.vsync: J6.27; also elsewhere on the board
/cpu/~lcd_reset: J6.3, R30.1; also elsewhere on the board
/lcd/led_a: C58.1, D16.1 (K), J6.29, U10.5 (OVP)
/lcd/led_driver_lx: D16.2 (A), L3.2, U10.1 (LX)
/lcd/led_k: J6.30, J6.31, J6.32, J6.33, R24.1, U10.3 (FB)
GND: C57.2, C58.2, J6.1, J6.35, R24.2, R30.2, U10.2 (GND); also elsewhere on the board

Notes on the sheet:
LCD PANEL CONNECTOR
LED DRIVER
maithoga 2.31 inch 35PIN LCD TFT LCD Screen ILI9342 Controller 320(RGB)*240 SPI/RGB 18Bit Interface https://www.aliexpress.com/item/1005006458533501.html
db0
This resistor avoids the need for software reset after power up, it is optional. Could be removed to save a tiny amount of power.
FIXME: this is broken, backlight can't be turned off
db17

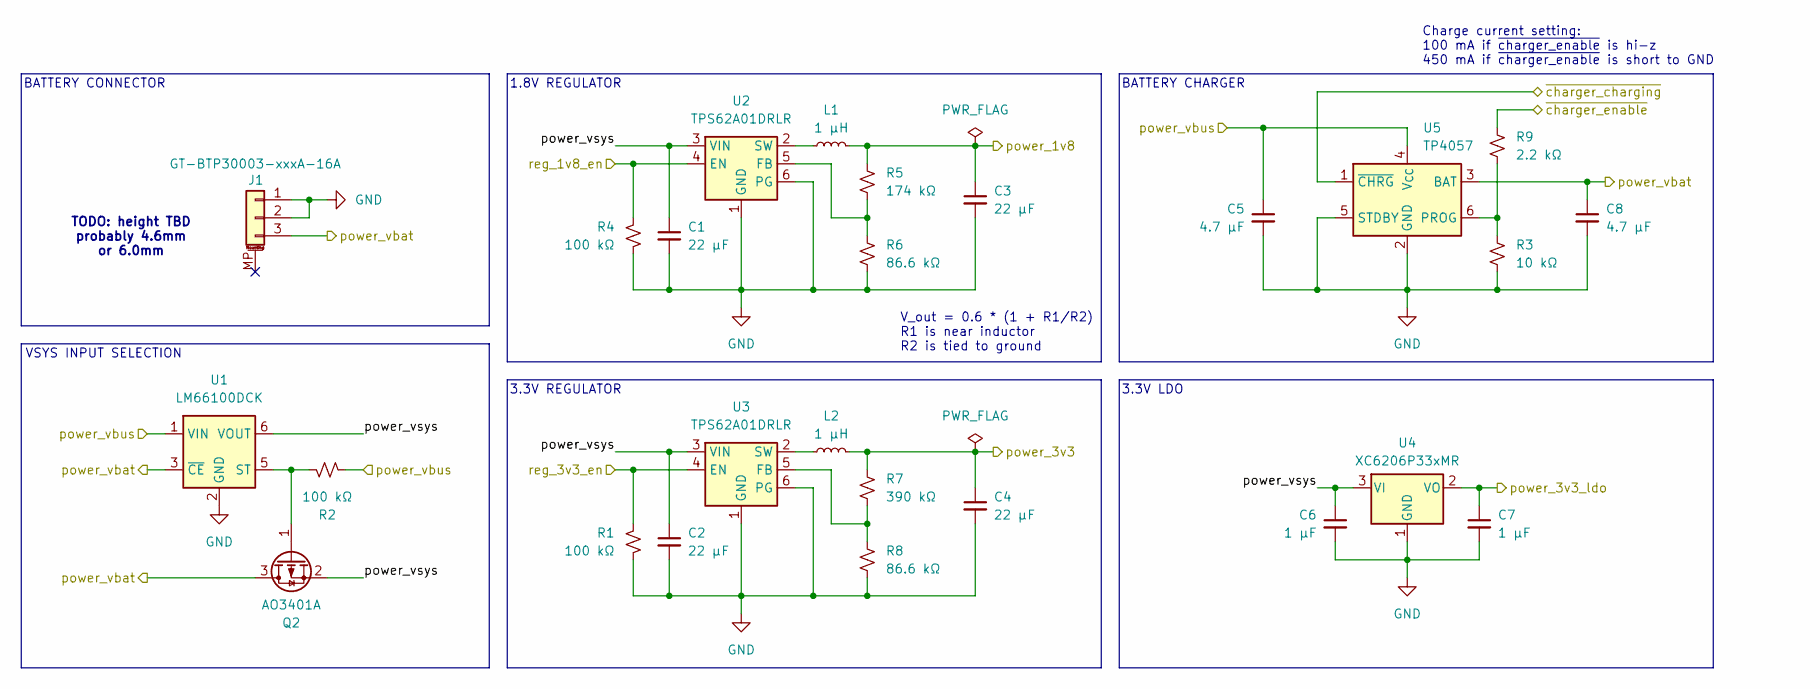
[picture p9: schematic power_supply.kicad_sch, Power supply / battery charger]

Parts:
C1, C2, C3, C4: 22 µF; C_0805_2012Metric; LCSC# C86816
C5, C8: 4.7 µF; C_0603_1608Metric; LCSC# C69335
C6, C7: 1 µF; C_0402_1005Metric; LCSC# C52923
J1: GT-BTP30003-xxxA-16A; Conn_GT-BTP30003-xxxxA-016A; LCSC# C41378737
L1, L2: 1 µH; L_0806_2016Metric; LCSC# C161082
Q2: AO3401A; SOT-23; LCSC# C347476
R1, R2, R4: 100 kΩ; R_0402_1005Metric; LCSC# C60491
R3: 10 kΩ; R_0402_1005Metric; LCSC# C60490
R5: 174 kΩ; R_0603_1608Metric; LCSC# C2933159
R6, R8: 86.6 kΩ; R_0603_1608Metric; LCSC# C3000725
R7: 390 kΩ; R_0603_1608Metric; LCSC# C23150
R9: 2.2 kΩ; R_0402_1005Metric; LCSC# C114762
U1: LM66100DCK; Texas_R-PDSO-G6; LCSC# C2869734
U2, U3: TPS62A01DRLR; SOT-563; LCSC# C5157937
U4: XC6206P33xMR; SOT-23-3; LCSC# C5446
U5: TP4057; TSOT-23-6; LCSC# C725791

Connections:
1V8: C3.1, L1.2, R5.1; also elsewhere on the board
3V3: C4.1, L2.2, R7.1; also elsewhere on the board
3V3_LDO: C7.1, U4.2 (VO); also elsewhere on the board
/cpu/reg_1v8_en: R4.1, U2.4 (EN); also elsewhere on the board
/cpu/reg_3v3_en: R1.1, U3.4 (EN); also elsewhere on the board
/cpu/~charger_charging: U5.1 (~CHRG); also elsewhere on the board
/cpu/~charger_enable: R9.1; also elsewhere on the board
/power/power_vsys: C1.1, C2.1, C6.1, Q2.2 (S), U1.6 (VOUT), U2.3 (VIN), U3.3 (VIN), U4.3 (VI)
GND: C1.2, C2.2, C3.2, C4.2, C5.2, C6.2, C7.2, C8.2, J1.1, J1.2, R1.2, R3.2, R4.2, R6.2, R8.2, U1.2 (GND), U2.1 (GND), U2.6 (PG), U3.1 (GND), U3.6 (PG), U4.1 (GND), U5.2 (GND), U5.5 (STDBY); also elsewhere on the board
unnamed: Q2.1 (G), R2.2, U1.5 (ST)
unnamed: R5.2, R6.1, U2.5 (FB)
unnamed: L1.1, U2.2 (SW)
unnamed: R7.2, R8.1, U3.5 (FB)
unnamed: L2.1, U3.2 (SW)
unnamed: R3.1, R9.2, U5.6 (PROG)
VBAT: C8.1, J1.3, Q2.3 (D), U1.3 (~CE), U5.3 (BAT); also elsewhere on the board
VBUS: C5.1, R2.1, U1.1 (VIN), U5.4 (V_{CC}); also elsewhere on the board

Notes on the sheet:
TODO: height TBD probably 4.6mm or 6.0mm
3.3V REGULATOR
V_out = 0.6 * (1 + R1/R2) R1 is near inductor R2 is tied to ground
1.8V REGULATOR
Charge current setting: 100 mA if ~{charger_enable} is hi-z 450 mA if ~{charger_enable} is short to GND
BATTERY CHARGER
BATTERY CONNECTOR
3.3V LDO
VSYS INPUT SELECTION

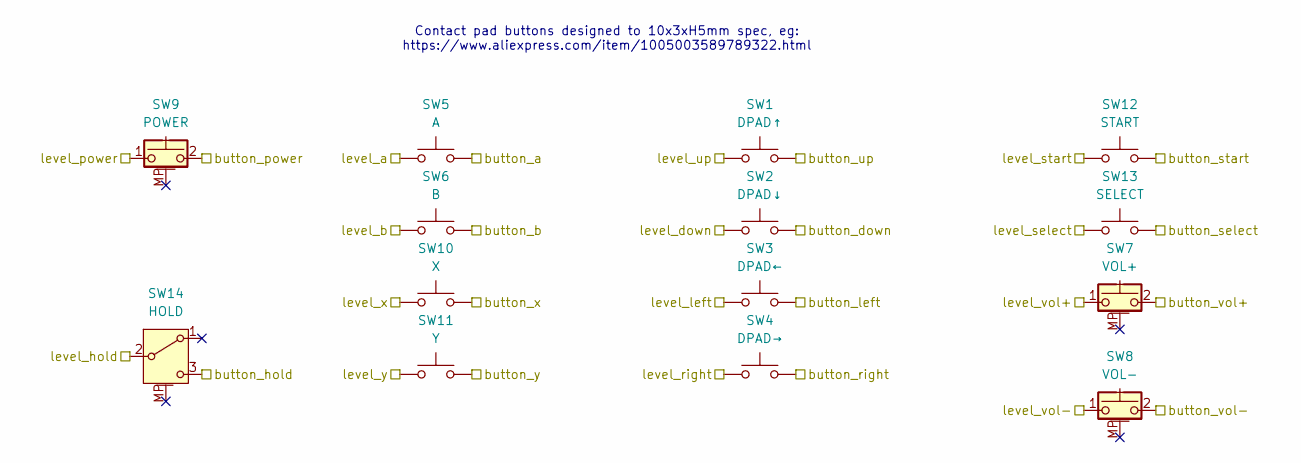
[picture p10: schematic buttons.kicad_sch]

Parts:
SW1: DPAD↑; Switch_ContactPad_10x3mm_Cross
SW2: DPAD↓; Switch_ContactPad_10x3mm_Cross
SW3: DPAD←; Switch_ContactPad_10x3mm_Cross
SW4: DPAD→; Switch_ContactPad_10x3mm_Cross
SW5: A; Switch_ContactPad_10x3mm_Cross
SW6: B; Switch_ContactPad_10x3mm_Cross
SW7: VOL+; Switch_XKB_TS-1010-C-A; LCSC# C318941
SW8: VOL-; Switch_XKB_TS-1010-C-A; LCSC# C318941
SW9: POWER; Switch_XKB_TS-1010-C-A; LCSC# C318941
SW10: X; Switch_ContactPad_10x3mm_Cross
SW11: Y; Switch_ContactPad_10x3mm_Cross
SW12: START; Switch_XUNPU_TS-1088-AR; LCSC# C720477
SW13: SELECT; Switch_XUNPU_TS-1088-AR; LCSC# C720477
SW14: HOLD; Switch_SHOUHAN_MSK12C02-HB; LCSC# C431541

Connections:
3V3_LDO: SW9.1, SW13.1; also elsewhere on the board
/button/button_a: SW5.2; also elsewhere on the board
/button/button_b: SW6.2; also elsewhere on the board
/button/button_down: SW2.2; also elsewhere on the board
/button/button_hold: SW14.3 (C); also elsewhere on the board
/button/button_left: SW3.2; also elsewhere on the board
/button/button_power: SW9.2; also elsewhere on the board
/button/button_right: SW4.2; also elsewhere on the board
/button/button_select: SW13.2; also elsewhere on the board
/button/button_start: SW12.2; also elsewhere on the board
/button/button_up: SW1.2; also elsewhere on the board
/button/button_vol+: SW7.2; also elsewhere on the board
/button/button_vol-: SW8.2; also elsewhere on the board
/button/button_x: SW10.2; also elsewhere on the board
/button/button_y: SW11.2; also elsewhere on the board
GND: SW1.1, SW2.1, SW3.1, SW4.1, SW5.1, SW6.1, SW7.1, SW8.1, SW10.1, SW11.1, SW12.1, SW14.2 (B); also elsewhere on the board

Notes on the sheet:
Contact pad buttons designed to 10x3xH5mm spec, eg: https://www.aliexpress.com/item/1005003589789322.html

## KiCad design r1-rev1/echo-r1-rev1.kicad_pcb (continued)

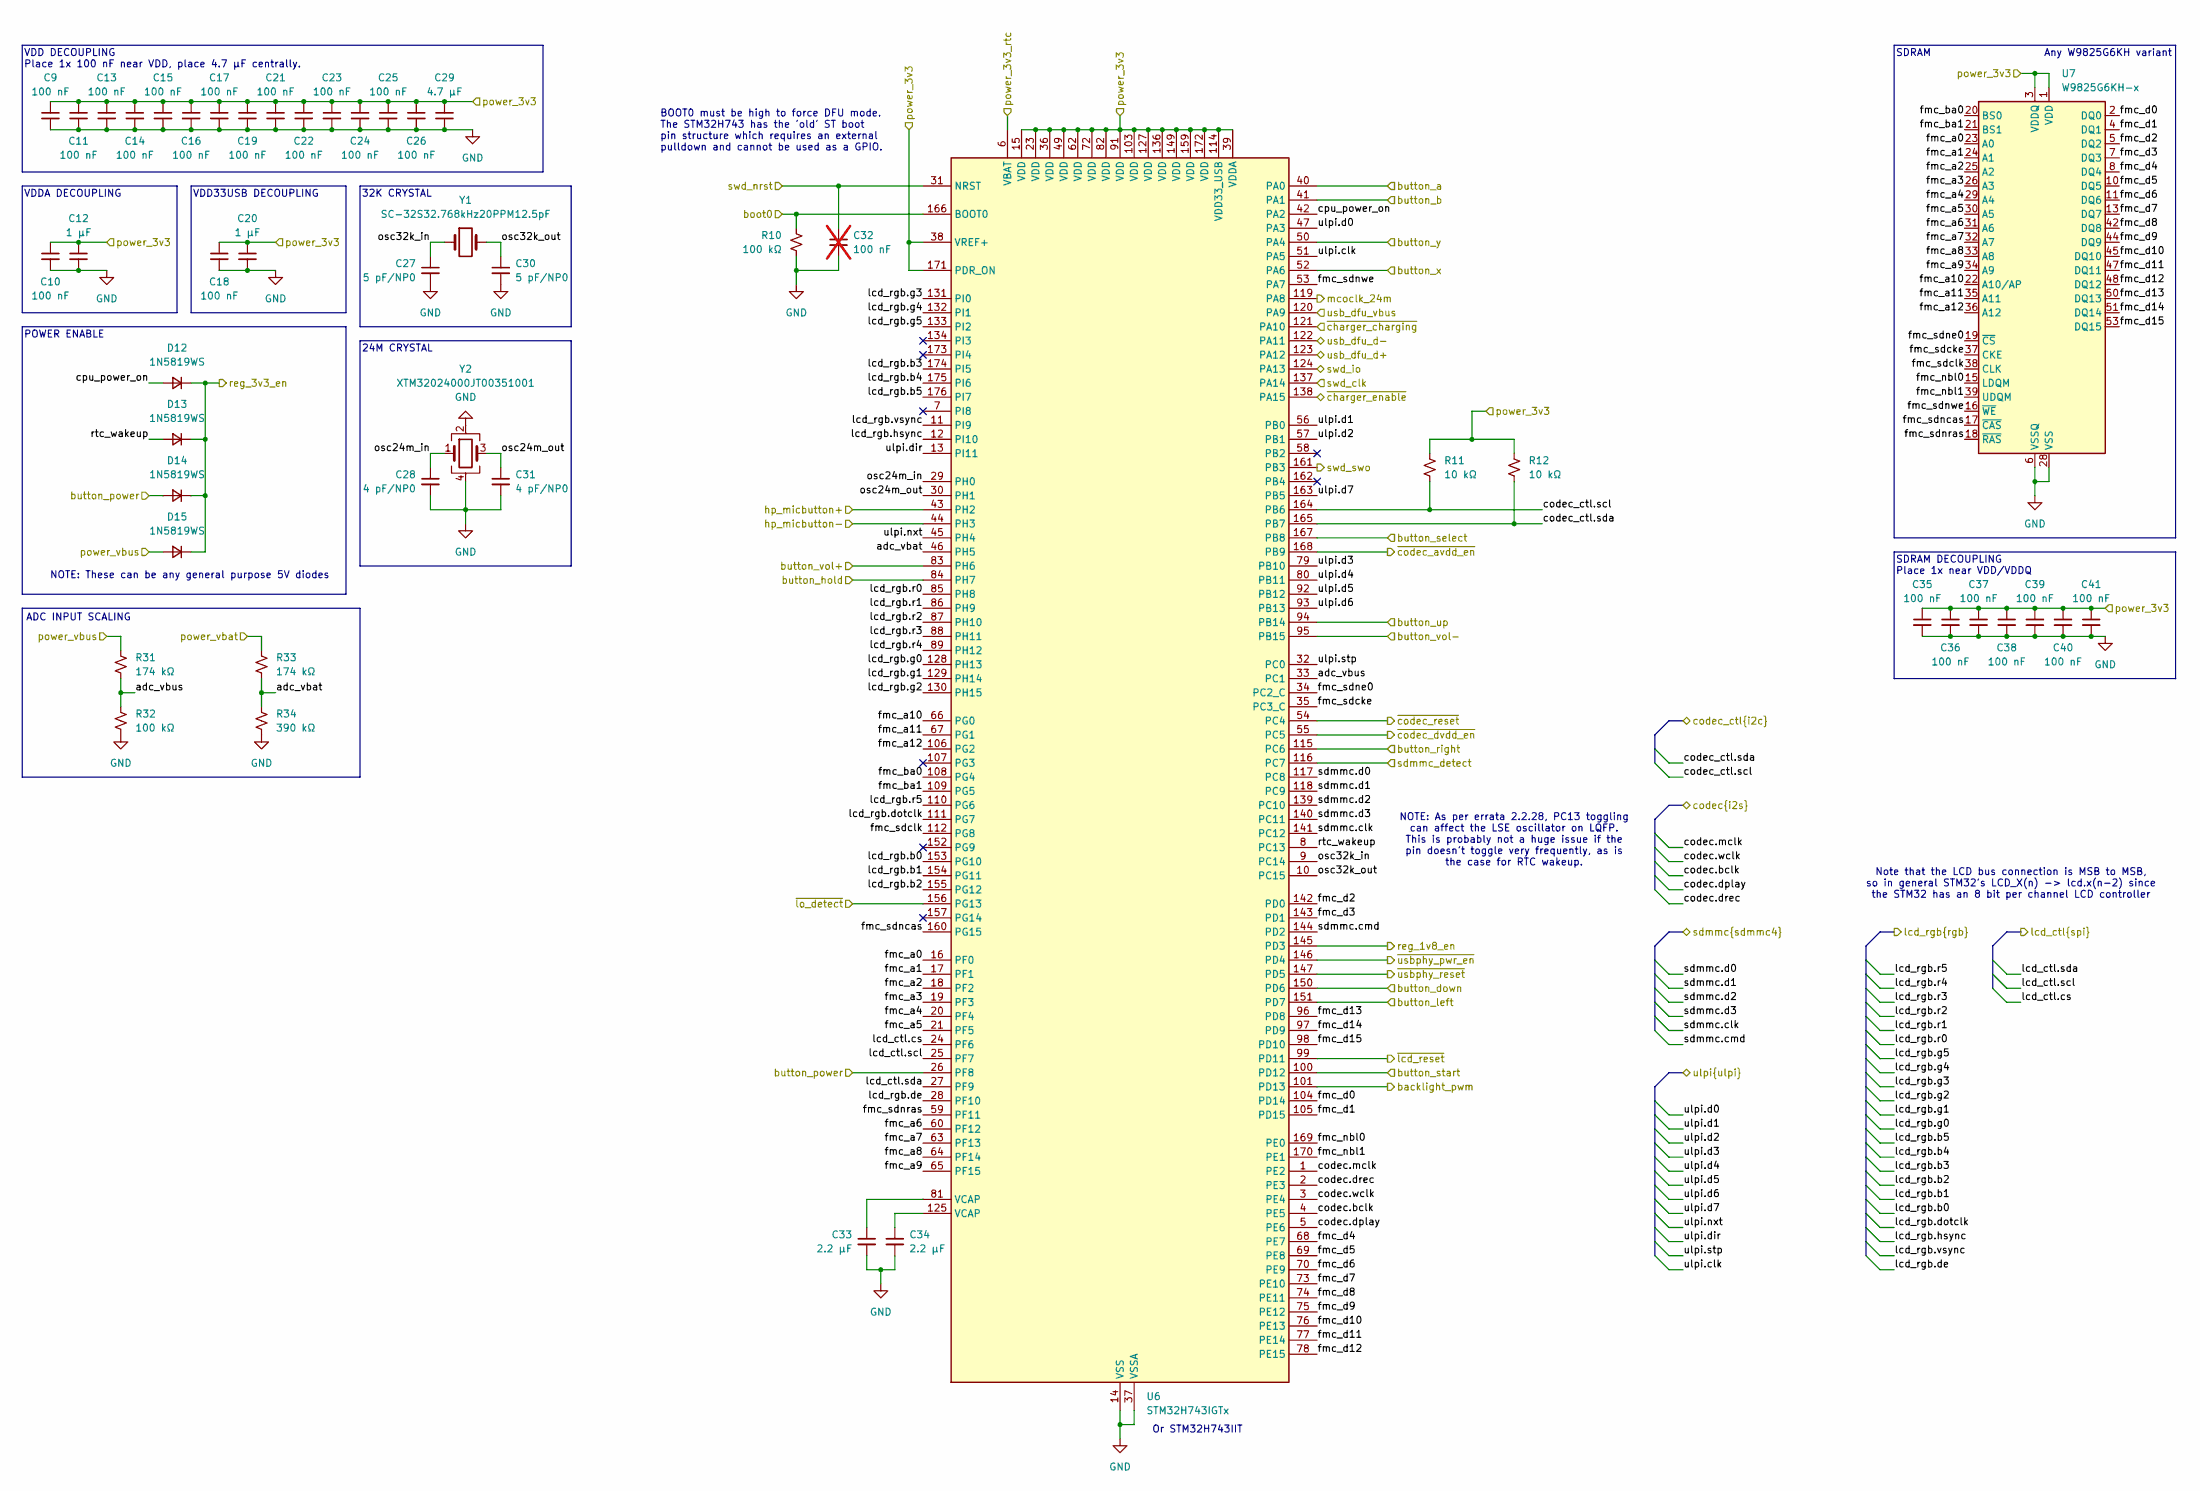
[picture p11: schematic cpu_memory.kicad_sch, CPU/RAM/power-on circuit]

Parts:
C9, C10, C11, C13, C14, C15, C16, C17, C18, C19, C21, C22, C23, C24, C25, C26, C35, C36, C37, C38, C39, C40, C41: 100 nF; C_0402_1005Metric; LCSC# C77020
C12, C20: 1 µF; C_0402_1005Metric; LCSC# C52923
C27, C30: 5 pF/NP0; C_0402_1005Metric; LCSC# C161328
C28, C31: 4 pF/NP0; C_0402_1005Metric; LCSC# C541337
C29: 4.7 µF; C_0603_1608Metric; LCSC# C69335
C32: 100 nF; C_0402_1005Metric; LCSC# C77020; not fitted
C33, C34: 2.2 µF; C_0603_1608Metric; LCSC# C57895
D12, D13, D14, D15: 1N5819WS; D_SOD-323; LCSC# C191023
R10, R32: 100 kΩ; R_0402_1005Metric; LCSC# C60491
R11, R12: 10 kΩ; R_0402_1005Metric; LCSC# C60490
R31, R33: 174 kΩ; R_0603_1608Metric; LCSC# C2933159
R34: 390 kΩ; R_0603_1608Metric; LCSC# C23150
U6: STM32H743IGTx; LQFP-176_24x24mm_P0.5mm; LCSC# C89597
U7: W9825G6KH-x; TSOP-II-54_22.2x10.16mm_P0.8mm; LCSC# C62246
Y1: SC-32S32.768kHz20PPM12.5pF; Crystal_SMD_3215-2Pin_3.2x1.5mm; LCSC# C97606
Y2: XTM32024000JT00351001; Crystal_SMD_3225-4Pin_3.2x2.5mm; LCSC# C37635376

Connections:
3V3: C9.1, C10.1, C11.1, C12.1, C13.1, C14.1, C15.1, C16.1, C17.1, C18.1, C19.1, C20.1, C21.1, C22.1, C23.1, C24.1, C25.1, C26.1, C29.1, C35.1, C36.1, C37.1, C38.1, C39.1, C40.1, C41.1, R11.1, R12.1, U6.15 (VDD), U6.23 (VDD), U6.36 (VDD), U6.38 (VREF+), U6.39 (VDDA), U6.49 (VDD), U6.62 (VDD), U6.72 (VDD), U6.82 (VDD), U6.91 (VDD), U6.103 (VDD), U6.114 (VDD33_USB), U6.127 (VDD), U6.136 (VDD), U6.149 (VDD), U6.159 (VDD), U6.171 (PDR_ON), U6.172 (VDD), U7.1 (VDD), U7.3 (VDDQ), U7.9 (VDDQ), U7.14 (VDD), U7.27 (VDD), U7.43 (VDDQ), U7.49 (VDDQ); also elsewhere on the board
3V3_LDO: U6.6 (VBAT); also elsewhere on the board
/audio/codec.bclk: U6.4 (PE5); also elsewhere on the board
/audio/codec.dplay: U6.5 (PE6); also elsewhere on the board
/audio/codec.drec: U6.2 (PE3); also elsewhere on the board
/audio/codec.mclk: U6.1 (PE2); also elsewhere on the board
/audio/codec.wclk: U6.3 (PE4); also elsewhere on the board
/audio/codec_ctl.scl: R11.2, U6.164 (PB6); also elsewhere on the board
/audio/codec_ctl.sda: R12.2, U6.165 (PB7); also elsewhere on the board
/audio/hp_micbutton+: U6.43 (PH2); also elsewhere on the board
/audio/hp_micbutton-: U6.44 (PH3); also elsewhere on the board
/audio/~avdd_en: U6.168 (PB9); also elsewhere on the board
/audio/~dvdd_en: U6.55 (PC5); also elsewhere on the board
/audio/~lo_detect: U6.156 (PG13); also elsewhere on the board
/audio/~reset: U6.54 (PC4); also elsewhere on the board
/button/button_a: U6.40 (PA0); also elsewhere on the board
/button/button_b: U6.41 (PA1); also elsewhere on the board
/button/button_down: U6.150 (PD6); also elsewhere on the board
/button/button_hold: U6.84 (PH7); also elsewhere on the board
/button/button_left: U6.151 (PD7); also elsewhere on the board
/button/button_power: D14.2 (A), U6.26 (PF8); also elsewhere on the board
/button/button_right: U6.115 (PC6); also elsewhere on the board
/button/button_select: R10.1, U6.166 (BOOT0), U6.167 (PB8); also elsewhere on the board
/button/button_start: U6.100 (PD12); also elsewhere on the board
/button/button_up: U6.94 (PB14); also elsewhere on the board
/button/button_vol+: U6.83 (PH6); also elsewhere on the board
/button/button_vol-: U6.95 (PB15); also elsewhere on the board
/button/button_x: U6.52 (PA6); also elsewhere on the board
/button/button_y: U6.50 (PA4); also elsewhere on the board
/cpu/adc_vbat: R33.2, R34.1, U6.46 (PH5)
/cpu/adc_vbus: R31.2, R32.1, U6.33 (PC1)
/cpu/backlight_pwm: U6.101 (PD13); also elsewhere on the board
/cpu/cpu_power_on: D12.2 (A), U6.42 (PA2)
/cpu/fmc_a0: U6.16 (PF0), U7.23 (A0)
/cpu/fmc_a1: U6.17 (PF1), U7.24 (A1)
/cpu/fmc_a2: U6.18 (PF2), U7.25 (A2)
/cpu/fmc_a3: U6.19 (PF3), U7.26 (A3)
/cpu/fmc_a4: U6.20 (PF4), U7.29 (A4)
/cpu/fmc_a5: U6.21 (PF5), U7.30 (A5)
/cpu/fmc_a6: U6.60 (PF12), U7.31 (A6)
/cpu/fmc_a7: U6.63 (PF13), U7.32 (A7)
/cpu/fmc_a8: U6.64 (PF14), U7.33 (A8)
/cpu/fmc_a9: U6.65 (PF15), U7.34 (A9)
/cpu/fmc_a10: U6.66 (PG0), U7.22 (A10/AP)
/cpu/fmc_a11: U6.67 (PG1), U7.35 (A11)
/cpu/fmc_a12: U6.106 (PG2), U7.36 (A12)
/cpu/fmc_ba0: U6.108 (PG4), U7.20 (BS0)
/cpu/fmc_ba1: U6.109 (PG5), U7.21 (BS1)
/cpu/fmc_d0: U6.104 (PD14), U7.2 (DQ0)
/cpu/fmc_d1: U6.105 (PD15), U7.4 (DQ1)
/cpu/fmc_d2: U6.142 (PD0), U7.5 (DQ2)
/cpu/fmc_d3: U6.143 (PD1), U7.7 (DQ3)
/cpu/fmc_d4: U6.68 (PE7), U7.8 (DQ4)
/cpu/fmc_d5: U6.69 (PE8), U7.10 (DQ5)
/cpu/fmc_d6: U6.70 (PE9), U7.11 (DQ6)
/cpu/fmc_d7: U6.73 (PE10), U7.13 (DQ7)
/cpu/fmc_d8: U6.74 (PE11), U7.42 (DQ8)
/cpu/fmc_d9: U6.75 (PE12), U7.44 (DQ9)
/cpu/fmc_d10: U6.76 (PE13), U7.45 (DQ10)
/cpu/fmc_d11: U6.77 (PE14), U7.47 (DQ11)
/cpu/fmc_d12: U6.78 (PE15), U7.48 (DQ12)
/cpu/fmc_d13: U6.96 (PD8), U7.50 (DQ13)
/cpu/fmc_d14: U6.97 (PD9), U7.51 (DQ14)
/cpu/fmc_d15: U6.98 (PD10), U7.53 (DQ15)
/cpu/fmc_nbl0: U6.169 (PE0), U7.15 (LDQM)
/cpu/fmc_nbl1: U6.170 (PE1), U7.39 (UDQM)
/cpu/fmc_sdcke: U6.35 (PC3_C), U7.37 (CKE)
/cpu/fmc_sdclk: U6.112 (PG8), U7.38 (CLK)
/cpu/fmc_sdncas: U6.160 (PG15), U7.17 (~CAS)
/cpu/fmc_sdne0: U6.34 (PC2_C), U7.19 (~CS)
/cpu/fmc_sdnras: U6.59 (PF11), U7.18 (~RAS)
/cpu/fmc_sdnwe: U6.53 (PA7), U7.16 (~WE)
/cpu/lcd_ctl.cs: U6.24 (PF6); also elsewhere on the board
/cpu/lcd_ctl.scl: U6.25 (PF7); also elsewhere on the board
/cpu/lcd_ctl.sda: U6.27 (PF9); also elsewhere on the board
/cpu/lcd_rgb.b0: U6.153 (PG10); also elsewhere on the board
/cpu/lcd_rgb.b1: U6.154 (PG11); also elsewhere on the board
/cpu/lcd_rgb.b2: U6.155 (PG12); also elsewhere on the board
/cpu/lcd_rgb.b3: U6.174 (PI5); also elsewhere on the board
/cpu/lcd_rgb.b4: U6.175 (PI6); also elsewhere on the board
/cpu/lcd_rgb.b5: U6.176 (PI7); also elsewhere on the board
/cpu/lcd_rgb.de: U6.28 (PF10); also elsewhere on the board
/cpu/lcd_rgb.dotclk: U6.111 (PG7); also elsewhere on the board
/cpu/lcd_rgb.g0: U6.128 (PH13); also elsewhere on the board
/cpu/lcd_rgb.g1: U6.129 (PH14); also elsewhere on the board
/cpu/lcd_rgb.g2: U6.130 (PH15); also elsewhere on the board
/cpu/lcd_rgb.g3: U6.131 (PI0); also elsewhere on the board
/cpu/lcd_rgb.g4: U6.132 (PI1); also elsewhere on the board
/cpu/lcd_rgb.g5: U6.133 (PI2); also elsewhere on the board
/cpu/lcd_rgb.hsync: U6.12 (PI10); also elsewhere on the board
/cpu/lcd_rgb.r0: U6.85 (PH8); also elsewhere on the board
/cpu/lcd_rgb.r1: U6.86 (PH9); also elsewhere on the board
/cpu/lcd_rgb.r2: U6.87 (PH10); also elsewhere on the board
/cpu/lcd_rgb.r3: U6.88 (PH11); also elsewhere on the board
/cpu/lcd_rgb.r4: U6.89 (PH12); also elsewhere on the board
/cpu/lcd_rgb.r5: U6.110 (PG6); also elsewhere on the board
/cpu/lcd_rgb.vsync: U6.11 (PI9); also elsewhere on the board
/cpu/mcoclk_24m: U6.119 (PA8); also elsewhere on the board
/cpu/osc24m_in: C28.1, U6.29 (PH0), Y2.1
/cpu/osc24m_out: C31.1, U6.30 (PH1), Y2.3
/cpu/osc32k_in: C27.1, U6.9 (PC14), Y1.1
/cpu/osc32k_out: C30.1, U6.10 (PC15), Y1.2
/cpu/reg_1v8_en: U6.145 (PD3); also elsewhere on the board
/cpu/reg_3v3_en: D12.1 (K), D13.1 (K), D14.1 (K), D15.1 (K); also elsewhere on the board
/cpu/rtc_wakeup: D13.2 (A), U6.8 (PC13)
/cpu/sdmmc.clk: U6.141 (PC12); also elsewhere on the board
/cpu/sdmmc.cmd: U6.144 (PD2); also elsewhere on the board
/cpu/sdmmc.d0: U6.117 (PC8); also elsewhere on the board
/cpu/sdmmc.d1: U6.118 (PC9); also elsewhere on the board
/cpu/sdmmc.d2: U6.139 (PC10); also elsewhere on the board
/cpu/sdmmc.d3: U6.140 (PC11); also elsewhere on the board
/cpu/sdmmc_detect: U6.116 (PC7); also elsewhere on the board
/cpu/swd_clk: U6.137 (PA14); also elsewhere on the board
/cpu/swd_io: U6.124 (PA13); also elsewhere on the board
/cpu/swd_nrst: C32.1, U6.31 (NRST); also elsewhere on the board
/cpu/swd_swo: U6.161 (PB3); also elsewhere on the board
/cpu/ulpi.clk: U6.51 (PA5); also elsewhere on the board
/cpu/ulpi.d0: U6.47 (PA3); also elsewhere on the board
/cpu/ulpi.d1: U6.56 (PB0); also elsewhere on the board
/cpu/ulpi.d2: U6.57 (PB1); also elsewhere on the board
/cpu/ulpi.d3: U6.79 (PB10); also elsewhere on the board
/cpu/ulpi.d4: U6.80 (PB11); also elsewhere on the board
/cpu/ulpi.d5: U6.92 (PB12); also elsewhere on the board
/cpu/ulpi.d6: U6.93 (PB13); also elsewhere on the board
/cpu/ulpi.d7: U6.163 (PB5); also elsewhere on the board
/cpu/ulpi.dir: U6.13 (PI11); also elsewhere on the board
/cpu/ulpi.nxt: U6.45 (PH4); also elsewhere on the board
/cpu/ulpi.stp: U6.32 (PC0); also elsewhere on the board
/cpu/usb_dfu_d+: U6.123 (PA12); also elsewhere on the board
/cpu/usb_dfu_d-: U6.122 (PA11); also elsewhere on the board
/cpu/~charger_charging: U6.121 (PA10); also elsewhere on the board
/cpu/~charger_enable: U6.138 (PA15); also elsewhere on the board
/cpu/~lcd_reset: U6.99 (PD11); also elsewhere on the board
/cpu/~usbphy_pwr_en: U6.146 (PD4); also elsewhere on the board
/cpu/~usbphy_reset: U6.147 (PD5); also elsewhere on the board
GND: C9.2, C10.2, C11.2, C12.2, C13.2, C14.2, C15.2, C16.2, C17.2, C18.2, C19.2, C20.2, C21.2, C22.2, C23.2, C24.2, C25.2, C26.2, C27.2, C28.2, C29.2, C30.2, C31.2, C32.2, C33.2, C34.2, C35.2, C36.2, C37.2, C38.2, C39.2, C40.2, C41.2, R10.2, R32.2, R34.2, U6.14 (VSS), U6.22 (VSS), U6.37 (VSSA), U6.48 (VSS), U6.61 (VSS), U6.71 (VSS), U6.90 (VSS), U6.102 (VSS), U6.113 (VSS), U6.126 (VSS), U6.135 (VSS), U6.148 (VSS), U6.158 (VSS), U7.6 (VSSQ), U7.12 (VSSQ), U7.28 (VSS), U7.41 (VSS), U7.46 (VSSQ), U7.52 (VSSQ), U7.54 (VSS), Y2.2, Y2.4; also elsewhere on the board
unnamed: C33.1, U6.81 (VCAP)
unnamed: C34.1, U6.125 (VCAP)
VBAT: R33.1; also elsewhere on the board
VBUS: D15.2 (A), R31.1, U6.120 (PA9); also elsewhere on the board

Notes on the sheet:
32K CRYSTAL
SDRAM DECOUPLING Place 1x near VDD/VDDQ
Note that the LCD bus connection is MSB to MSB, so in general STM32's LCD_X(n) -> lcd.x(n-2) since the STM32 has an 8 bit per channel LCD controller
BOOT0 must be high to force DFU mode. The STM32H743 has the 'old' ST boot pin structure which requires an external pulldown and cannot be used as a GPIO.
Or STM32H743IIT
NOTE: These can be any general purpose 5V diodes
ADC INPUT SCALING
VDD33USB DECOUPLING
NOTE: As per errata 2.2.28, PC13 toggling can affect the LSE oscillator on LQFP. This is probably not a huge issue if the pin doesn't toggle very frequently, as is the case for RTC wakeup.
VDD DECOUPLING Place 1x 100 nF near VDD, place 4.7 µF centrally.
VDDA DECOUPLING
24M CRYSTAL
SDRAM
POWER ENABLE
Any W9825G6KH variant

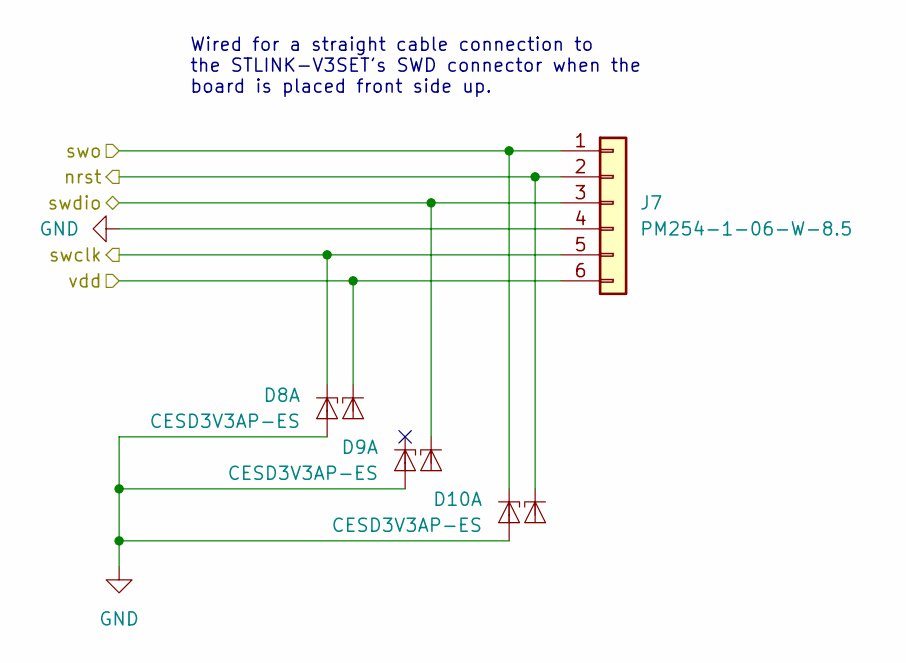
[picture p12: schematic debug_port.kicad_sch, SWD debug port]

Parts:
D8, D9, D10: CESD3V3AP-ES; SOT-23; LCSC# C5199223
J7: PM254-1-06-W-8.5; PinSocket_1x06_P2.54mm_Horizontal; LCSC# C2897388

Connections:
3V3: D8.2 (K2), J7.6; also elsewhere on the board
/cpu/swd_clk: D8.1 (K1), J7.5; also elsewhere on the board
/cpu/swd_io: D9.2 (K2), J7.3; also elsewhere on the board
/cpu/swd_nrst: D10.2 (K2), J7.2; also elsewhere on the board
/cpu/swd_swo: D10.1 (K1), J7.1; also elsewhere on the board
GND: D8.3 (A), D9.3 (A), D10.3 (A), J7.4; also elsewhere on the board

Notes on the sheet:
Wired for a straight cable connection to the STLINK-V3SET's SWD connector when the board is placed front side up.

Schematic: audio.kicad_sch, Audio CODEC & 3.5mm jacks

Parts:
C46, C48, C50, C53: 100 nF; C_0402_1005Metric; LCSC# C77020
C47, C49, C51, C54: 10 µF; C_0603_1608Metric; LCSC# C91606
C52: 10 nF/NP0; C_0603_1608Metric; LCSC# C85973
C55, C56: 10 µF; CP_Elec_4x5.4; LCSC# C72485
D5: PESD3V3L2BT; SOT-23; LCSC# C2923380
D6, D7, D11: CESD3V3AP-ES; SOT-23; LCSC# C5199223
J4: HP_3.5mm; Jack_3.5mm_HCTL_HC-PJ-320A-4P-D; LCSC# C5372851
J5: LO_3.5mm; Jack_3.5mm_HCTL_HC-PJ-320A-4P-D; LCSC# C5372851
NT1, NT2: NetTie_2; NetTie_0.15mm_SMD
Q6, Q7: AO3401A; SOT-23; LCSC# C347476
R20, R21, R22, R26: 100 kΩ; R_0402_1005Metric; LCSC# C60491
R23: 2.2 kΩ; R_0402_1005Metric; LCSC# C114762
R25: 1 MΩ; R_0402_1005Metric; LCSC# C138033
U9: TLV320AIC3104; Texas_RHB0032E_VQFN-32-1EP_5x5mm_P0.5mm_EP3.45x3.45mm_Therm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; LCSC# C181753

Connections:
1V8: Q7.2 (S), R22.1; also elsewhere on the board
3V3: C48.1, C49.1, U9.7 (IOVDD); also elsewhere on the board
3V3_LDO: Q6.2 (S), R21.1, R25.1; also elsewhere on the board
/audio/avdd: C50.1, C51.1, C53.1, C54.1, Q6.3 (D), U9.18 (DRVDD), U9.24 (DRVDD), U9.25 (AVDD)
/audio/codec.bclk: U9.2 (BCLK); also elsewhere on the board
/audio/codec.dplay: U9.4 (DIN); also elsewhere on the board
/audio/codec.drec: U9.5 (DOUT); also elsewhere on the board
/audio/codec.mclk: U9.1 (MCLK); also elsewhere on the board
/audio/codec.wclk: U9.3 (WCLK); also elsewhere on the board
/audio/codec_ctl.scl: U9.8 (SCL); also elsewhere on the board
/audio/codec_ctl.sda: U9.9 (SDA); also elsewhere on the board
/audio/dvdd: C46.1, C47.1, Q7.3 (D), U9.32 (DVDD)
/audio/hp_com: D7.1 (K1), J4.T, NT2.2, U9.20 (HPLCOM), U9.22 (HPRCOM)
/audio/hp_left: D6.1 (K1), J4.R1, U9.19 (HPLOUT)
/audio/hp_mic: C52.1, D7.2 (K2), J4.S, NT1.2, R23.2, U9.14 (MIC2L/LINE2L/MICDET)
/audio/hp_micbutton+: NT1.1; also elsewhere on the board
/audio/hp_micbutton-: NT2.1; also elsewhere on the board
/audio/hp_right: D6.2 (K2), J4.R2, U9.23 (HPROUT)
/audio/lo_left: C55.1, U9.27 (LEFT_LOP)
/audio/lo_right: C56.1, U9.29 (RIGHT_LOP)
/audio/micbias: R23.1, U9.15 (MICBIAS)
/audio/~avdd_en: Q6.1 (G), R21.2; also elsewhere on the board
/audio/~dvdd_en: Q7.1 (G), R22.2; also elsewhere on the board
/audio/~lo_detect: R26.1; also elsewhere on the board
/audio/~reset: R20.1, U9.31 (~RESET); also elsewhere on the board
GND: C46.2, C47.2, C48.2, C49.2, C50.2, C51.2, C53.2, C54.2, D5.3 (GND), D6.3 (A), D7.3 (A), D11.3 (A), J5.T, R20.2, U9.6 (DVSS), U9.10 (MIC1LP/LINE1LP), U9.11 (MIC1LM/LINE1LM), U9.12 (MIC1RP/LINE1RM), U9.13 (MIC1RM/LINE1RM), U9.17 (AVSS1), U9.21 (DRVSS), U9.26 (AVSS2), U9.33 (DRVSS); also elsewhere on the board
unnamed: C56.2, D5.1 (IO1), J5.R2
unnamed: C55.2, D5.2 (IO2), J5.R1
unnamed: D11.2 (K2), J5.S, R25.2, R26.2
unnamed: C52.2, U9.16 (MIC2R/LINE2R)

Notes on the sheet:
HEADPHONE JACK
CODEC AVDD DECOUPLING
CODEC AVDD/DRVDD SWITCH
CODEC DRVDD DECOUPLING Place near pin 24
/!\ WARNING /!\ These jacks jave a wrong, nonstandard pinout and don't work with normal equipment. To get audio you need to construct a 4-pin TRRS male-to-female adapter. CTIA wiring diagram: (Player) <-> (Adapter) Tip <-> Ring2 Ring1 <-> Tip Ring2 <-> Ring1 Sleeve <-> Sleeve
Headphone detection is done over I2C using the codec's inbuilt detection function
CODEC DVDD DECOUPLING
LINE-OUT JACK
CODEC IOVDD DECOUPLING
Since the jack's ground is HPCOM (1.35V), micbias should always be connected to AVDD (3.3V) to give a sufficient bias voltage.
AUDIO CODEC
Recommended power sequencing: 1. IOVDD first 2. AVDD/DRVDD second 3. DVDD last and within 5ms of AVDD rise 4. ~{RESET} held low until all supplies stable.
CODEC DVDD SWITCH

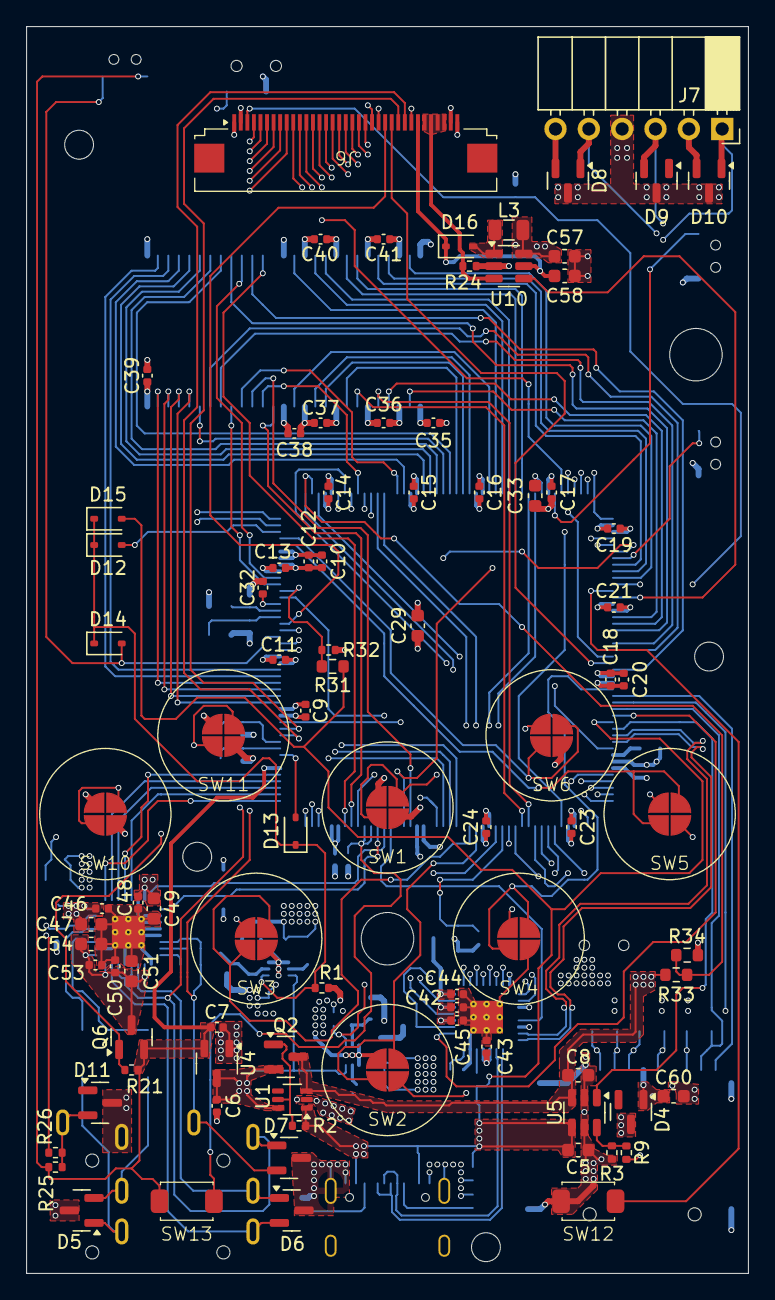
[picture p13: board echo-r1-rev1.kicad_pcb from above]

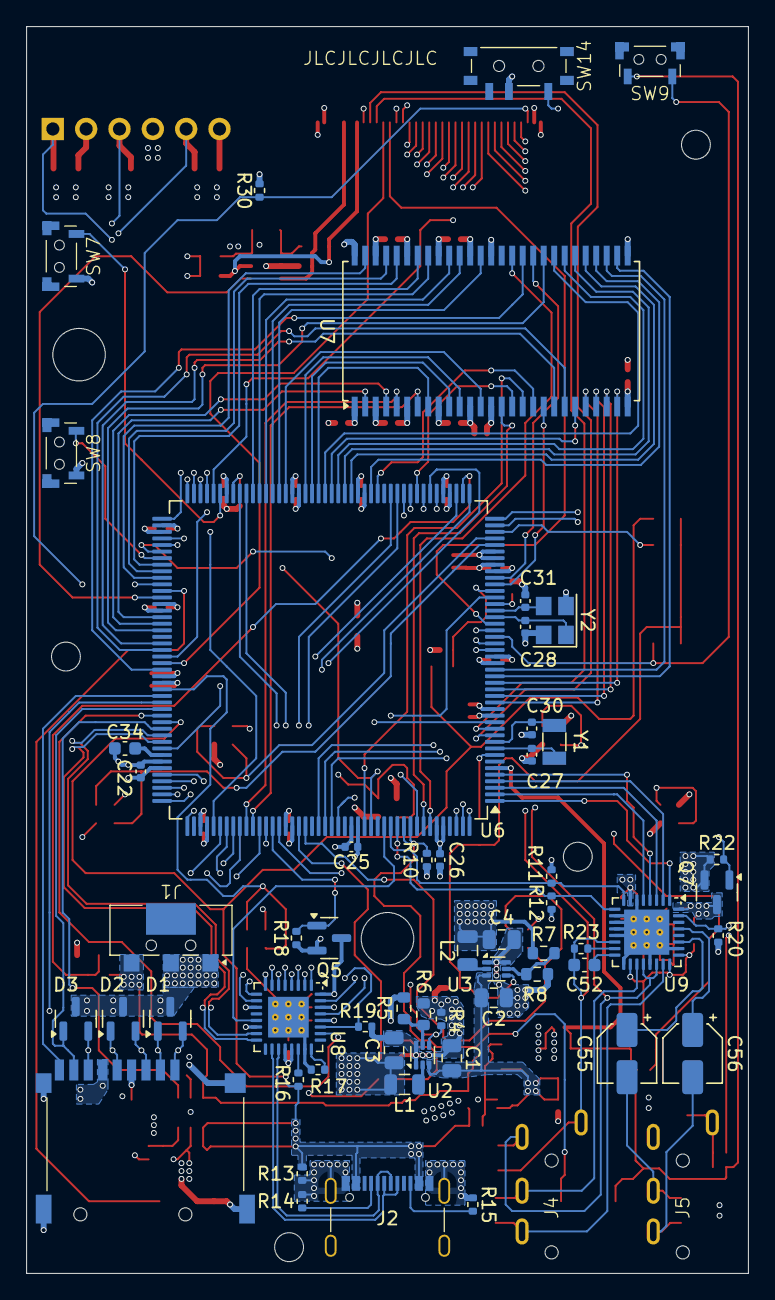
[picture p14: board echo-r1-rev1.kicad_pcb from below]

Board: 6 copper layers, 55.0 x 95.0 mm, 154 parts (58 on the bottom side), 171 nets.

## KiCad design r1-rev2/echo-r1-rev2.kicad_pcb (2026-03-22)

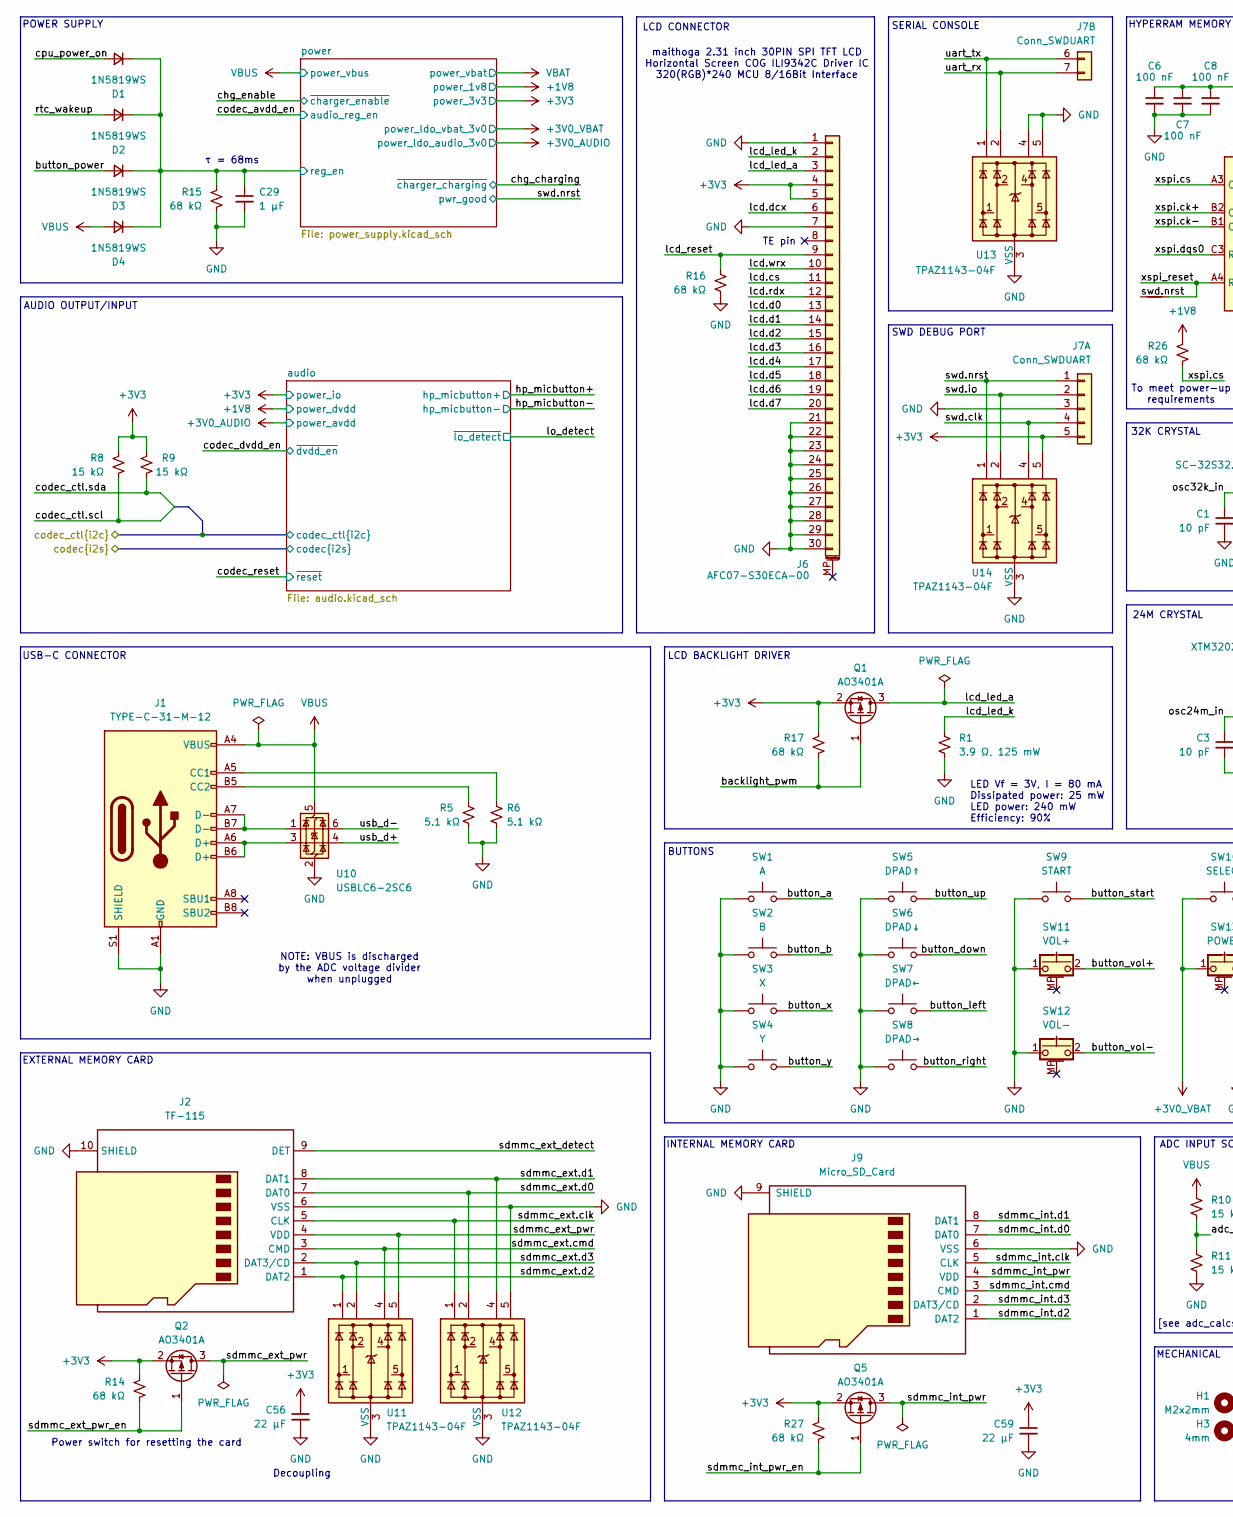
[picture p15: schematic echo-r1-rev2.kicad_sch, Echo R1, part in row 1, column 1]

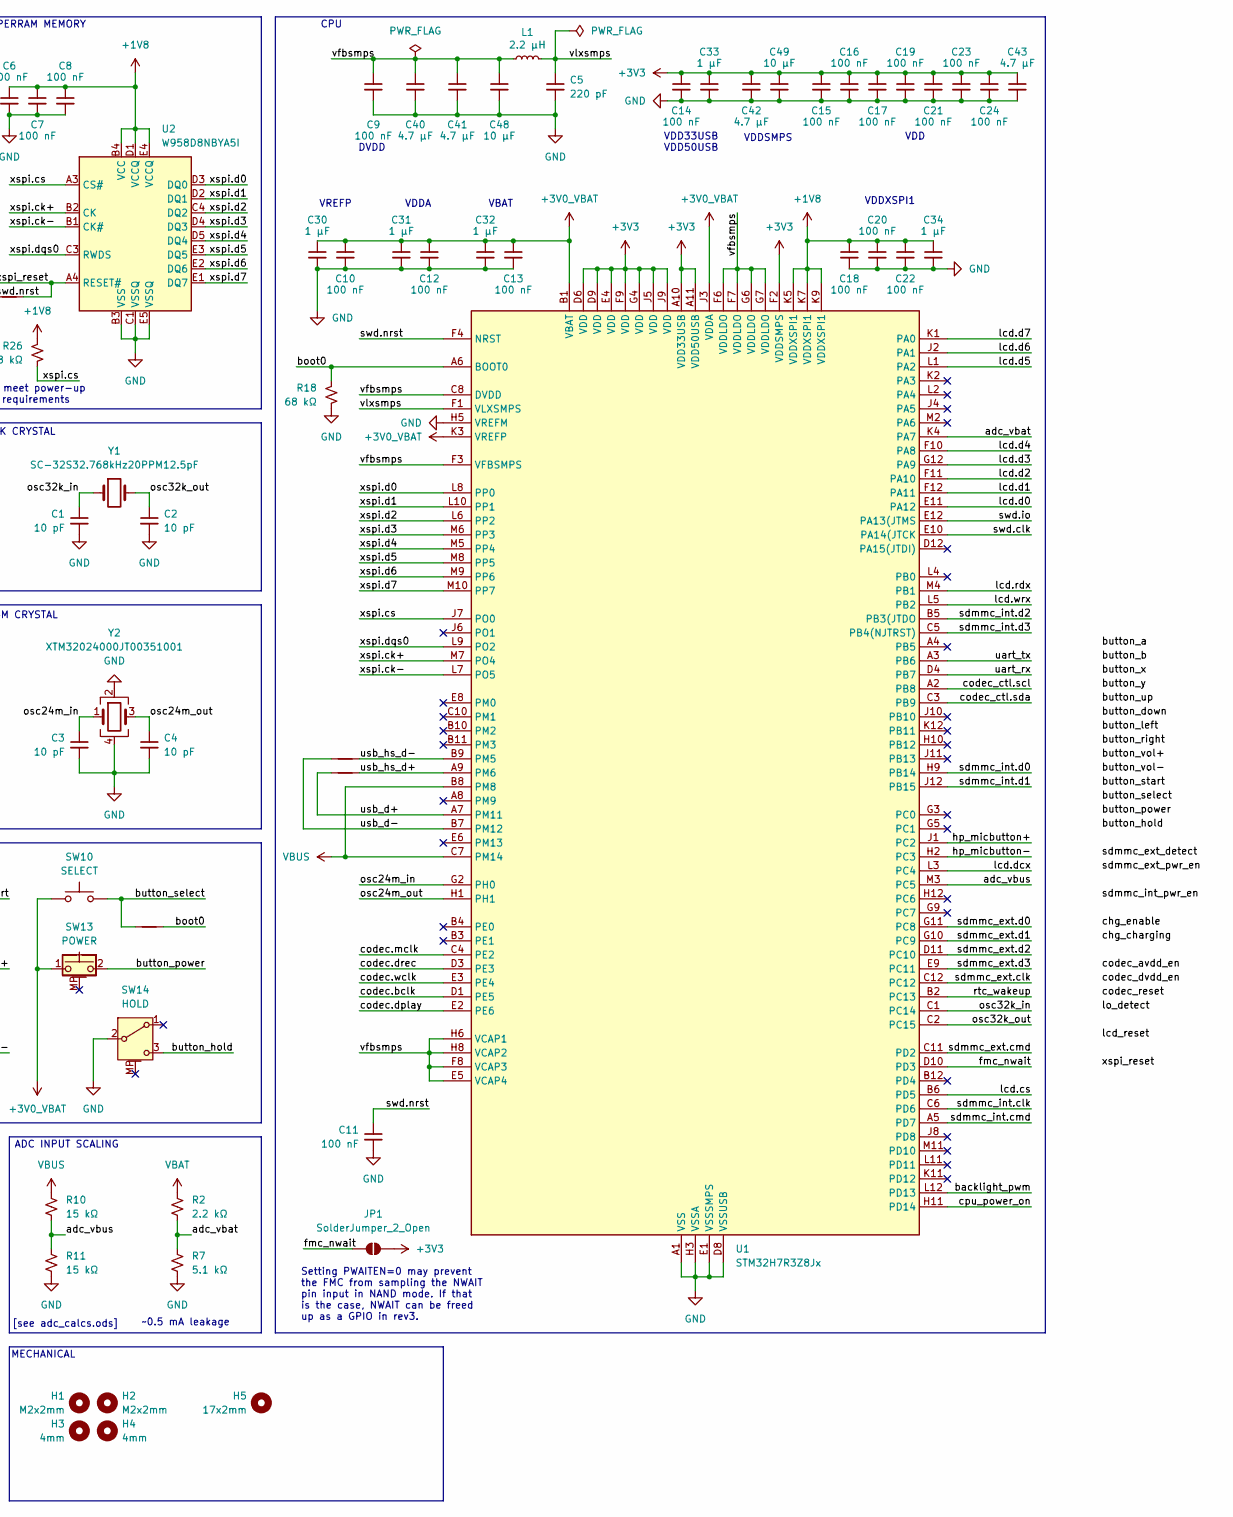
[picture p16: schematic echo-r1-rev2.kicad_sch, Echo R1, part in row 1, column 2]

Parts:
C1, C2, C3, C4: 10 pF; C_0402_1005Metric
C5: 220 pF; C_0402_1005Metric
C6, C7, C8, C9, C10, C11, C12, C13, C14, C15, C16, C17, C18, C19, C20, C21, C22, C23, C24: 100 nF; C_0402_1005Metric
C29, C30, C31, C32, C33, C34: 1 µF; C_0402_1005Metric
C40, C41, C42, C43: 4.7 µF; C_0805_2012Metric
C48, C49: 10 µF; C_0805_2012Metric
C56, C59: 22 µF; C_0805_2012Metric
D1, D2, D3, D4: 1N5819WS; D_SOD-323
H1, H2: M2x2mm; MountingHole_2.2mm_M2
H3, H4: 4mm; MountingHole_4mm
H5: 17x2mm; Slot_17x2mm
J1: TYPE-C-31-M-12; USB_C-Hroparts-TYPE-C-31-M-12
J2: TF-115; microSD_XUNPU_TF-115
J6: AFC07-S30ECA-00; Conn_Jushuo_AFC07-S30ECA-00_RTL
J7: Conn_SWDUART; PinHeader_1x07_P2.54mm_Vertical
J9: Micro_SD_Card; microSD_XUNPU_TF-102-15
JP1: SolderJumper_2_Open; SolderJumper-2_P1.3mm_Open_RoundedPad1.0x1.5mm
L1: 2.2 µH; L_Changjiang_FNR3015S
NT1, NT2: NetTie_2; NetTie_0.15mm_SMD
NT3, NT4: NetTie_2; NetTie_0.10mm_SMD
Q1, Q2, Q5: AO3401A; SOT-23
R1: 3.9 Ω, 125 mW; R_0805_2012Metric
R2: 2.2 kΩ; R_0402_1005Metric
R5, R6, R7: 5.1 kΩ; R_0402_1005Metric
R8, R9, R10, R11: 15 kΩ; R_0402_1005Metric
R14, R15, R16, R17, R18, R26, R27: 68 kΩ; R_0402_1005Metric
SW1: A; Switch_SHOUHAN_TS3735PA
SW2: B; Switch_SHOUHAN_TS3735PA
SW3: X; Switch_SHOUHAN_TS3735PA
SW4: Y; Switch_SHOUHAN_TS3735PA
SW5: DPAD↑; Switch_SHOUHAN_TS3735PA
SW6: DPAD↓; Switch_SHOUHAN_TS3735PA
SW7: DPAD←; Switch_SHOUHAN_TS3735PA
SW8: DPAD→; Switch_SHOUHAN_TS3735PA
SW9: START; Switch_SHOUHAN_TS3735PA
SW10: SELECT; Switch_SHOUHAN_TS3735PA
SW11: VOL+; Switch_HROPARTS_K2-1112SA-A4DW-01
SW12: VOL-; Switch_HROPARTS_K2-1112SA-A4DW-01
SW13: POWER; Switch_HROPARTS_K2-1112SA-A4DW-01
SW14: HOLD; Switch_SHOUHAN_MSK12C02-HB
U1: STM32H7R3Z8Jx; UFBGA-144_10x10mm_Layout12x12_P0.8mm
U2: W958D8NBYA5I; TFBGA-24_6x8mm_Layout5x5_P1.0mm_Ball0.4mm
U10: USBLC6-2SC6; SOT-23-6
U11, U12, U13, U14: TPAZ1143-04F; TECHPUBLIC_UDFN-10_1.0x2.5mm_P0.5mm
Y1: SC-32S32.768kHz20PPM12.5pF; Crystal_SMD_3215-2Pin_3.2x1.5mm
Y2: XTM32024000JT00351001; Crystal_SMD_3225-4Pin_3.2x2.5mm

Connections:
+1V8: C6.1, C7.1, C8.1, C18.1, C20.1, C22.1, C34.1, R26.1, U1.K5 (VDDXSPI1), U1.K7 (VDDXSPI1), U1.K9 (VDDXSPI1), U2.B4 (VCC), U2.D1 (VCCQ), U2.E4 (VCCQ); also elsewhere on the board
+3V0_VBAT: C10.1, C12.1, C13.1, C30.1, C31.1, C32.1, SW10.1, SW13.1, U1.B1 (VBAT), U1.J3 (VDDA), U1.K3 (VREFP); also elsewhere on the board
+3V3: C14.1, C15.1, C16.1, C17.1, C19.1, C21.1, C23.1, C24.1, C33.1, C42.1, C43.1, C49.1, C56.1, C59.1, J6.4, J6.5, J7.5, JP1.2 (B), Q1.2 (S), Q2.2 (S), Q5.2 (S), R8.1, R9.1, R14.1, R17.1, R27.1, U1.A10 (VDD33USB), U1.A11 (VDD50USB), U1.D6 (VDD), U1.D9 (VDD), U1.E4 (VDD), U1.F2 (VDDSMPS), U1.F9 (VDD), U1.G4 (VDD), U1.J5 (VDD), U1.J9 (VDD), U14.5; also elsewhere on the board
/adc_vbat: R2.2, R7.1, U1.K4 (PA7)
/adc_vbus: R10.1, R11.1, U1.M3 (PC5)
/backlight_pwm: Q1.1 (G), R17.2, U1.L12 (PD13)
/boot0: NT2.2, R18.1, U1.A6 (BOOT0)
/button_a: SW1.2
/button_b: SW2.2
/button_down: SW6.2
/button_hold: SW14.3 (C)
/button_left: SW7.2
/button_power: D3.2 (A), SW13.2
/button_right: SW8.2
/button_select: NT2.1, SW10.2
/button_start: SW9.2
/button_up: SW5.2
/button_vol+: SW11.2
/button_vol-: SW12.2
/button_x: SW3.2
/button_y: SW4.2
/codec.bclk: U1.D1 (PE5); also elsewhere on the board
/codec.dplay: U1.E2 (PE6); also elsewhere on the board
/codec.drec: U1.D3 (PE3); also elsewhere on the board
/codec.mclk: U1.C4 (PE2); also elsewhere on the board
/codec.wclk: U1.E3 (PE4); also elsewhere on the board
/codec_ctl.scl: R8.2, U1.A2 (PB8); also elsewhere on the board
/codec_ctl.sda: R9.2, U1.C3 (PB9); also elsewhere on the board
/cpu_power_on: D1.2 (A), U1.H11 (PD14)
/fmc_nwait: JP1.1 (A), U1.D10 (PD3)
/hp_micbutton+: U1.J1 (PC2); also elsewhere on the board
/hp_micbutton-: U1.H2 (PC3); also elsewhere on the board
/lcd.cs: J6.11, U1.B6 (PD5)
/lcd.d0: J6.13, U1.E11 (PA12)
/lcd.d1: J6.14, U1.F12 (PA11)
/lcd.d2: J6.15, U1.F11 (PA10)
/lcd.d3: J6.16, U1.G12 (PA9)
/lcd.d4: J6.17, U1.F10 (PA8)
/lcd.d5: J6.18, U1.L1 (PA2)
/lcd.d6: J6.19, U1.J2 (PA1)
/lcd.d7: J6.20, U1.K1 (PA0)
/lcd.dcx: J6.6, U1.L3 (PC4)
/lcd.rdx: J6.12, U1.M4 (PB1)
/lcd.wrx: J6.10, U1.L5 (PB2)
/lcd_led_a: J6.3, Q1.3 (D)
/lcd_led_k: J6.2, R1.1
/lcd_reset: J6.9, R16.1
/osc24m_in: C3.1, U1.G2 (PH0), Y2.1
/osc24m_out: C4.1, U1.H1, Y2.3
/osc32k_in: C1.1, U1.C1 (PC14), Y1.1
/osc32k_out: C2.1, U1.C2 (PC15), Y1.2
/power/reg_en: C29.1, D1.1 (K), D2.1 (K), D3.1 (K), D4.1 (K), R15.1; also elsewhere on the board
/rtc_wakeup: D2.2 (A), U1.B2 (PC13)
/sdmmc_ext.clk: J2.5 (CLK), U1.C12, U12.1
/sdmmc_ext.cmd: J2.3 (CMD), U1.C11 (PD2), U11.4
/sdmmc_ext.d0: J2.7 (DAT0), U1.G11 (PC8), U12.2
/sdmmc_ext.d1: J2.8 (DAT1), U1.G10 (PC9), U12.4
/sdmmc_ext.d2: J2.1 (DAT2), U1.D11 (PC10), U11.1
/sdmmc_ext.d3: J2.2 (DAT3/CD), U1.E9 (PC11), U11.2
/sdmmc_ext_detect: J2.9 (DET)
/sdmmc_ext_pwr: J2.4 (VDD), Q2.3 (D), U11.5
/sdmmc_ext_pwr_en: Q2.1 (G), R14.2
/sdmmc_int.clk: J9.5 (CLK), U1.C6 (PD6)
/sdmmc_int.cmd: J9.3 (CMD), U1.A5 (PD7)
/sdmmc_int.d0: J9.7 (DAT0), U1.H9 (PB14)
/sdmmc_int.d1: J9.8 (DAT1), U1.J12 (PB15)
/sdmmc_int.d2: J9.1 (DAT2), U1.B5 (PB3(JTDO)
/sdmmc_int.d3: J9.2 (DAT3/CD), U1.C5 (PB4(NJTRST))
/sdmmc_int_pwr: J9.4 (VDD), Q5.3 (D)
/sdmmc_int_pwr_en: Q5.1 (G), R27.2
/swd.clk: J7.4, U1.E10 (PA14(JTCK), U14.4
/swd.io: J7.2, U1.E12 (PA13(JTMS), U14.2
/swd.nrst: C11.1, J7.1, NT1.1, U1.F4 (NRST), U14.1; also elsewhere on the board
/uart_rx: J7.7 (Pin_2), U1.D4 (PB7), U13.2
/uart_tx: J7.6 (Pin_1), U1.A3 (PB6), U13.1
/usb_d+: NT4.1, U1.A7 (PM11), U10.4 (I/O2)
/usb_d-: NT3.1, U1.B7 (PM12), U10.6 (I/O1)
/usb_hs_d+: NT4.2, U1.A9 (PM6)
/usb_hs_d-: NT3.2, U1.B9 (PM5)
/vfbsmps: C9.1, C40.1, C41.1, C48.1, L1.1, U1.C8 (DVDD), U1.E5 (VCAP4), U1.F3 (VFBSMPS), U1.F6 (VDDLDO), U1.F7 (VDDLDO), U1.F8 (VCAP3), U1.G6 (VDDLDO), U1.G7 (VDDLDO), U1.H6 (VCAP1), U1.H8 (VCAP2)
/vlxsmps: C5.1, L1.2, U1.F1 (VLXSMPS)
/xspi.ck+: U1.M7 (PO4), U2.B2 (CK)
/xspi.ck-: U1.L7 (PO5), U2.B1 (CK#)
/xspi.cs: R26.2, U1.J7 (PO0), U2.A3 (CS#)
/xspi.d0: U1.L8 (PP0), U2.D3 (DQ0)
/xspi.d1: U1.L10 (PP1), U2.D2 (DQ1)
/xspi.d2: U1.L6 (PP2), U2.C4 (DQ2)
/xspi.d3: U1.M6 (PP3), U2.D4 (DQ3)
/xspi.d4: U1.M5 (PP4), U2.D5 (DQ4)
/xspi.d5: U1.M8 (PP5), U2.E3 (DQ5)
/xspi.d6: U1.M9 (PP6), U2.E2 (DQ6)
/xspi.d7: U1.M10 (PP7), U2.E1 (DQ7)
/xspi.dqs0: U1.L9 (PO2), U2.C3 (RWDS)
/xspi_reset: NT1.2, U2.A4 (RESET#)
GND: C1.2, C2.2, C3.2, C4.2, C5.2, C6.2, C7.2, C8.2, C9.2, C10.2, C11.2, C12.2, C13.2, C14.2, C15.2, C16.2, C17.2, C18.2, C19.2, C20.2, C21.2, C22.2, C23.2, C24.2, C29.2, C30.2, C31.2, C32.2, C33.2, C34.2, C40.2, C41.2, C42.2, C43.2, C48.2, C49.2, C56.2, C59.2, J1.A1 (GND), J1.A12 (GND), J1.B1 (GND), J1.B12 (GND), J1.S1 (SHIELD), J2.6 (VSS), J2.10 (SHIELD), J6.1, J6.7, J6.21, J6.22, J6.23, J6.24, J6.25, J6.26, J6.27, J6.28, J6.29, J6.30, J7.3, J9.6 (VSS), J9.9 (SHIELD), R1.2, R5.1, R6.1, R7.2, R11.2, R15.2, R16.2, R18.2, SW1.1, SW2.1, SW3.1, SW4.1, SW5.1, SW6.1, SW7.1, SW8.1, SW9.1, SW11.1, SW12.1, SW14.2 (B), U1.A1 (VSS), U1.A12 (VSS), U1.C9 (VSS), U1.D2 (VSS), U1.D5 (VSS), U1.D7 (VSS), U1.D8 (VSSUSB), U1.E1 (VSSSMPS), U1.E7 (VSS), U1.F5 (VSS), U1.G1 (VSS), U1.G8 (VSS), U1.H3 (VSSA), U1.H4 (VSS), U1.H5 (VREFM), U1.H7 (VSS), U1.K6 (VSS), U1.K8 (VSS), U1.K10 (VSS), U1.M1 (VSS), U1.M12 (VSS), U2.B3 (VSS), U2.C1 (VSSQ), U2.E5 (VSSQ), U10.2 (GND), U11.3 (VSS), U11.6 (NC), U11.7 (NC), U11.8 (VSS), U11.9 (NC), U11.10 (NC), U12.3 (VSS), U12.5, U12.6 (NC), U12.7 (NC), U12.8 (VSS), U12.9 (NC), U12.10 (NC), U13.3 (VSS), U13.4, U13.5, U13.6 (NC), U13.7 (NC), U13.8 (VSS), U13.9 (NC), U13.10 (NC), U14.3 (VSS), U14.6 (NC), U14.7 (NC), U14.8 (VSS), U14.9 (NC), U14.10 (NC), Y2.2, Y2.4; also elsewhere on the board
unnamed: J1.A5 (CC1), R6.2
unnamed: J1.B5 (CC2), R5.2
unnamed: J1.A6 (D+), J1.B6 (D+), U10.3 (I/O2)
unnamed: J1.A7 (D-), J1.B7 (D-), U10.1 (I/O1)
VBAT: R2.1; also elsewhere on the board
VBUS: D4.2 (A), J1.A4 (VBUS), J1.A9 (VBUS), J1.B4 (VBUS), J1.B9 (VBUS), R10.2, U1.B8 (PM8), U1.C7 (PM14), U10.5 (VBUS); also elsewhere on the board

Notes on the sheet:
CPU
Decoupling
BUTTONS
VDDSMPS
VDD33USB VDD50USB
SERIAL CONSOLE
VDD
maithoga 2.31 inch 30PIN SPI TFT LCD Horizontal Screen COG ILI9342C Driver IC 320(RGB)*240 MCU 8/16Bit Interface
To meet power-up requirements
[see adc_calcs.ods]
MECHANICAL
ADC INPUT SCALING
TE pin
LED Vf = 3V, I = 80 mA Dissipated power: 25 mW LED power: 240 mW Efficiency: 90%
LCD CONNECTOR
Power switch for resetting the card
LCD BACKLIGHT DRIVER
τ = 68ms
VDDXSPI1
DVDD
EXTERNAL MEMORY CARD
24M CRYSTAL
USB-C CONNECTOR
Setting PWAITEN=0 may prevent the FMC from sampling the NWAIT pin input in NAND mode. If that is the case, NWAIT can be freed up as a GPIO in rev3.
VBAT
NOTE: VBUS is discharged by the ADC voltage divider when unplugged
VREFP
POWER SUPPLY
VDDA
32K CRYSTAL
SWD DEBUG PORT
HYPERRAM MEMORY
AUDIO OUTPUT/INPUT
INTERNAL MEMORY CARD
~0.5 mA leakage

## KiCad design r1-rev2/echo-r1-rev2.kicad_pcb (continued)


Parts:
C35, C36, C37, C38: 1 µF; C_0402_1005Metric
C44, C45, C46, C47: 4.7 µF; C_0805_2012Metric
C57, C58: 22 µF; C_0805_2012Metric
J5: GT-BTP30003-xxxA-16A; Conn_GT-BTP30003-xxxxA-016A
J8: BATT; PinHeader_1x02_P2.54mm_Vertical
L2, L3: 2.2 µH; L_Changjiang_FNR3015S
Q3: AO3401A; SOT-23
R3: 2.2 kΩ; R_0402_1005Metric
R12, R13: 15 kΩ; R_0402_1005Metric
R19, R20, R21, R22, R23: 68 kΩ; R_0402_1005Metric
U4: LM66100DCK; Texas_R-PDSO-G6
U5, U6: TPS62A01DRLR; SOT-563
U7, U8: AP2125K-3.0; SOT-23-5
U9: TP4057; TSOT-23-6

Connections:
+1V8: C57.1, L2.2, R21.1; also elsewhere on the board
+3V0_AUDIO: C38.1, U8.5 (VOUT); also elsewhere on the board
+3V0_VBAT: C37.1, U7.5 (VOUT); also elsewhere on the board
+3V3: C36.1, C58.1, L3.2, R20.1, U8.1 (VIN); also elsewhere on the board
/chg_charging: U9.1 (~CHRG)
/chg_enable: R3.1
/codec_avdd_en: U8.3 (CE)
/power/power_vsys: C35.1, C45.1, C46.1, Q3.2 (S), U4.6 (VOUT), U5.3 (VIN), U6.3 (VIN), U7.1 (VIN), U7.3 (CE)
/power/reg_en: U5.4 (EN), U6.4 (EN); also elsewhere on the board
/swd.nrst: U5.6 (PG), U6.6 (PG); also elsewhere on the board
GND: C35.2, C36.2, C37.2, C38.2, C44.2, C45.2, C46.2, C47.2, C57.2, C58.2, J5.1, J5.2, J8.2, R12.2, R13.2, R22.2, R23.2, U4.2 (GND), U5.1 (GND), U6.1 (GND), U7.2 (GND), U7.4 (NC), U8.2 (GND), U8.4 (NC), U9.2 (GND), U9.5 (STDBY); also elsewhere on the board
unnamed: Q3.1 (G), R19.2, U4.5 (ST)
unnamed: R21.2, R22.1, R23.1, U5.5 (FB)
unnamed: L2.1, U5.2 (SW)
unnamed: R12.1, R20.2, U6.5 (FB)
unnamed: L3.1, U6.2 (SW)
unnamed: R3.2, R13.1, U9.6 (PROG)
VBAT: C47.1, J5.3, J8.1, Q3.3 (D), U4.3 (~CE), U9.3 (BAT); also elsewhere on the board
VBUS: C44.1, R19.1, U4.1 (VIN), U9.4 (V_{CC}); also elsewhere on the board

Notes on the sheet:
TODO: height TBD probably 4.6mm or 6.0mm
3.3V REGULATOR
34kΩ effective
V_out = 0.6 * (1 + R1/R2) R1 is near inductor R2 is tied to ground
1.8V REGULATOR
Charge current setting: ~75 mA if ~{charger_enable} is hi-z 450 mA if ~{charger_enable} is short to GND
BATTERY CHARGER
BATTERY CONNECTOR
3.0V AUDIO LDO
3.0V VBAT/VREF LDO
VSYS INPUT SELECTION


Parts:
C25, C26, C27, C28: 100 nF; C_0402_1005Metric
C39: 1 µF; C_0402_1005Metric
C50, C51, C52, C53: 10 µF; C_0805_2012Metric
C54, C55: 10 µF/Al; CP_Elec_4x5.4
D5, D6: ESD5Z3.3C; D_SOD-523
J3: HP_3.5mm; Jack_3.5mm_HCTL_HC-PJ-320A-4P-D
J4: LO_3.5mm; Jack_3.5mm_HCTL_HC-PJ-320A-4P-D
NT5, NT6: NetTie_2; NetTie_0.15mm_SMD
Q4: AO3401A; SOT-23
R4: 2.2 kΩ; R_0402_1005Metric
R24, R25: 68 kΩ; R_0402_1005Metric
U3: TLV320AIC3104; Texas_RHB0032E_VQFN-32-1EP_5x5mm_P0.5mm_EP3.45x3.45mm_Therm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
U15, U16: TPAZ1143-04F; TECHPUBLIC_UDFN-10_1.0x2.5mm_P0.5mm

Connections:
+1V8: Q4.2 (S), R25.1; also elsewhere on the board
+3V0_AUDIO: U3.18 (DRVDD), U3.24 (DRVDD), U3.25 (AVDD); also elsewhere on the board
+3V3: C26.1, C51.1, U3.7 (IOVDD); also elsewhere on the board
/audio/avdd: C27.1, C28.1, C52.1, C53.1
/audio/dvdd: C25.1, C50.1, Q4.3 (D), U3.32 (DVDD)
/audio/hp_com: J3.R2, NT6.2, U3.20 (HPLCOM), U3.22 (HPRCOM), U15.2
/audio/hp_left: J3.T, U3.19 (HPLOUT), U15.5
/audio/hp_mic: C39.1, J3.S, NT5.2, R4.2, U3.14 (MIC2L/LINE2L/MICDET), U15.1
/audio/hp_right: J3.R1, U3.23 (HPROUT), U15.4
/audio/lo_left: C55.1, U3.27 (LEFT_LOP)
/audio/lo_right: C54.1, U3.29 (RIGHT_LOP)
/audio/micbias: R4.1, U3.15 (MICBIAS)
/codec.bclk: U3.2 (BCLK); also elsewhere on the board
/codec.dplay: U3.4 (DIN); also elsewhere on the board
/codec.drec: U3.5 (DOUT); also elsewhere on the board
/codec.mclk: U3.1 (MCLK); also elsewhere on the board
/codec.wclk: U3.3 (WCLK); also elsewhere on the board
/codec_ctl.scl: U3.8 (SCL); also elsewhere on the board
/codec_ctl.sda: U3.9 (SDA); also elsewhere on the board
/codec_dvdd_en: Q4.1 (G), R25.2
/codec_reset: R24.1, U3.31 (~RESET)
/hp_micbutton+: NT5.1; also elsewhere on the board
/hp_micbutton-: NT6.1; also elsewhere on the board
/lo_detect: J4.S, U16.1
GND: C25.2, C26.2, C27.2, C28.2, C50.2, C51.2, C52.2, C53.2, D5.2 (A), D6.2 (A), J4.R2, R24.2, U3.6 (DVSS), U3.10 (MIC1LP/LINE1LP), U3.11 (MIC1LM/LINE1LM), U3.12 (MIC1RP/LINE1RM), U3.13 (MIC1RM/LINE1RM), U3.17 (AVSS1), U3.21 (DRVSS), U3.26 (AVSS2), U3.33 (DRVSS), U15.3 (VSS), U15.6 (NC), U15.7 (NC), U15.8 (VSS), U15.9 (NC), U15.10 (NC), U16.2, U16.3 (VSS), U16.4, U16.5, U16.6 (NC), U16.7 (NC), U16.8 (VSS), U16.9 (NC), U16.10 (NC); also elsewhere on the board
unnamed: C54.2, D5.1 (K), J4.R1
unnamed: C55.2, D6.1 (K), J4.T
unnamed: C39.2, U3.16 (MIC2R/LINE2R)

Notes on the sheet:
HEADPHONE JACK
CODEC AVDD DECOUPLING
CODEC DRVDD DECOUPLING Place near pin 24
Headphone detection is done over I2C using the codec's inbuilt detection function
CODEC DVDD DECOUPLING
LINE-OUT JACK
CODEC IOVDD DECOUPLING
Since the jack's ground is HPCOM (1.35V), micbias should always be connected to AVDD (3.3V) to give a sufficient bias voltage.
AUDIO CODEC
Recommended power sequencing: 1. IOVDD first 2. AVDD/DRVDD second 3. DVDD last and within 5ms of AVDD rise 4. ~{RESET} held low until all supplies stable.
CODEC DVDD SWITCH



Board: 6 copper layers, 140.0 x 120.6 mm, 153 parts (72 on the bottom side), 111 nets.

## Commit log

2025-02-22 Initial Echo R1 release
    [audio.kicad_sch, bom.ods, buttons.kicad_sch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]
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2025-05-08 Create R1 case, design LCD module support
    [Echo-R1.FCStd]
2025-05-08 R1 case: Add holes for buttons and supports for PCB
    [Echo-R1-Rev1.FCStd]
2025-05-08 R1 case: refactoring to make the CAD model nicer
    - Replaced VarSet with a spreadsheet: VarSet has annoying
    limitations, for example you can't rename properties after
    creating them.
    - Made use of reference geometry and symmetries to cut down
    on the number of variables and simplify sketches.
    - Added tolerance to the side walls to give clearance for
    the PCB.
    [Echo-R1-Rev1.FCStd]
2025-05-08 R1 case: finish most of the front side
    - Holes cut and toleranced for ports and side buttons
    - Added tolerancing on LCD module
    All the major features are now present for the front half
    of the case, although there's still nothing to affix the
    two halves of the case together (the back still needs to
    be modeled, but it will be a lot simpler than the front).
    Thickness is now 18mm -- the LCD assembly takes up a lot
    of space on the Z axis and the SWD port adds around 3mm.
    [Echo-R1-Rev1.FCStd]
2025-06-11 Update to KiCAD 9.0
    [audio.kicad_sch, buttons.kicad_sch, cpu_memory.kicad_sch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]
2025-06-11 R1-Rev1: remove VBUS discharge resistor
    This is not needed since there is a path through the ADC
    voltage divider to discharge VBUS -- and realistically
    the battery charger should also discharge VBUS even with
    no resistive path to ground.
    [bom.ods, cpu_memory.kicad_sch, echo-r1.kicad_pcb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]
2025-06-11 R1-Rev1: replace SY7200A LED driver with AP2502 current limiter
    The SY7200A is a boost converter designed for series LED
    strings, which require a high drive voltage. The external
    circuitry allows some input power to pass through to the
    output -- which is normally not a problem for LED strings
    because this low voltage is not enough to overcome their
    combined voltage drop.
    However, the LCD uses 4 LEDs in parallel, and this low
    voltage is enough to light the LEDs while the converter
    is disabled, so the backlight can't be turned off.
    Fix this by using the AP2502 4-channel current limiter
    instead, which is basically a low side switch. LEDs are
    powered directly from 3.3V, and each is independent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
    [bom.ods, echo-r1.kicad_pcb, lcd.kicad_sch]
2025-06-11 R1-Rev1: remove old backlight components from BOM
    [bom.ods]
2025-06-11 R1-Rev1: fork Rev1 files into a subdirectory
    [Echo-R1-Rev1.FCStd, audio.kicad_sch, bom.ods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]
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2025-06-11 R1-Rev2: add pin assignment sheets for STM32H7R3Z8xx chips
    [pins_stm32h7r3z8j6.ods, pins_stm32h7r3z8t6.ods]
2025-06-11 R1-Rev2: WIP redesign with STM32H7R3Z8J6
    The H7R3 has a bunch of features that greatly simplify the design:
    support for HyperRAM, which requires far fewer pins than SDRAM and
    is more power efficient; this frees up the FMC to interface with the
    display in 8-bit 8080 MCU mode; and there is a built-in USB HS PHY,
    removing the need for an external PHY.
    The huge reduction in signal count allows for a smaller pin count
    package -- only 144 pins. HyperRAM only comes in BGA packages so it
    makes sense to also use the UFBGA-144 package for the CPU, which
    takes up less than 1/4 of the board area of an LQFP-176 package.
    [audio.kicad_sch, buttons.kicad_sch, cpu_memory.kicad_sch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]
2025-06-11 R1-Rev2: continue with redesign, update and simplify schematic
    - Consolidate small sheets (ports, etc) onto one page
    - Add placeholders for STM32 external components
    - Add power switch on SD card for resetting it
    - Fix oversized input capacitors on voltage regulators
    - Get rid of unique 1M resistor used in line-out detection
    - Remove SOT23 TVS diodes (will be replaced by another package)
    - Update LCD connector symbol for new 30pin screen
    [audio.kicad_sch, echo-r1.kicad_pcb, echo-r1.kicad_sch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]
2025-06-11 R1-Rev2: optimize resistor values
    - Resistors used for the ADC dividers were way too high; I didn't
    take into account how the RC constant affected ADC performance
    so the conversion accuracy was probably poor. The new values are
    based on ST's recommendations and the theoretical resolution is
    computed in a spreadsheet.
    - Simplify LO detect, originally I had the idea of a "wake on jack
    insert" feature but this is not possible for the headphone jack
    because it is only polled over I2C. The reason for the big 1M
    resistor that was there in Rev1 was to keep the effect on ground
    minimal. If the MCU is powered up then a simple hi-z input with
    internal pullup does the job better.
    - St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
    [adc_calcs.ods, audio.kicad_sch, echo-r1.kicad_sch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]
2025-06-11 R1-Rev2: strip LCSC part numbers from schematic
    These will be managed in a separate BOM spreadsheet going forward.
    [audio.kicad_sch, echo-r1.kicad_sch, power_supply.kicad_sch]
2025-06-11 R1-Rev2: connect decoupling caps on STM32
    [echo-r1.kicad_sch]
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2025-06-11 R1-Rev2: remove bulk capacitor on RAM side of memory bus
    There is already a 1 uF on the STM32 side, having extra bulk
    capacitance is probably unnecessary considering the chips will
    be placed very close to each other.
    [echo-r1.kicad_sch]
2025-06-11 R1-Rev2: convert buttons to SMD metal dome switches
    Rubber domes increase mechanical complexity since they need to
    be aligned and supported in the case to prevent them from going
    off-center, and they require a lot of vertical space (~5mm).
    Domes are also an additional component that has to be sourced
    separately.
    In contrast, prepackaged metal dome switches are normal SMD parts
    and can be sourced and assembled alongside electronic components.
    They are also much, much thinner and mechanical design is simpler.
    [echo-r1.kicad_sch]
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2025-06-11 R1-Rev2: finish STM32 pin assignment and fix ERC issues
    - Expanded LCD bus from 8 to 16 pins so it can be accessed by DMA2D.
    - Added RDX pin to LCD bus to allow read access
    - Added UART console port for easier access to debug logging
    - Shorted USB HS and FS PHYs for DFU mode support
    - Connected all GPIOs and peripheral pins
    [audio.kicad_sch, echo-r1.kicad_sch, pins_stm32h7r3z8j6.ods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]
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2025-06-11 R1-Rev2: add LCD backlight driver
    The LEDs in the backlight will be in series since there are only
    two pins, but it's not clear how many LEDs are there and without
    that it's not possible to set the right current limit.
    [echo-r1.kicad_sch, pins_stm32h7r3z8j6.ods]
2025-06-11 R1-Rev2: update PCB stackup and board outline
    The new board stackup uses alternate signal and ground layers,
    being careful not to cross thicker cores. This should keep the
    electric fields smaller, and in theory, is better for EMI than
    the old stackup which didn't pay attention to the space between
    layers. Power will be routed on signal layers.
    The board outline is now rounded generously for compatibility
    with CNC machined cases (which require rounded inner corners).
    It is also now toleranced back from the inner edge of the case,
    but I may pull it back further still.
    There were some minor disreprancies from the intended JLC stackup
    which have also been fixed, not that it really matters sinc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
    [echo-r1.kicad_pcb]
2025-06-11 R1-Rev2: initial mechanical layout
    - Outline front side of case, LCD module, and cable
    - Lay out LCD, since it requires 12'oclock viewing angle a slot is
    required to thread the ribbon cable through to the back plane.
    - Place buttons, HP/LO jacks, and USB port
    - Make the power/volume buttons larger
    - Remove old button footprints
    [echo-r1.kicad_pcb, echo-r1.kicad_sch]
2025-06-11 R1-Rev2: update backlight driver circuit
    There are 4 LEDs in parallel in the LCD backlight, sharing the
    same cathode/anode, so the backlight can be driven with just a
    MOSFET and resistor. (A PMOS is used to avoid having to add a
    new unique component.)
    [echo-r1.kicad_sch]
2025-06-11 R1-Rev2: use FMC NAND mode for 8-bit 8080 LCD interface
    NAND mode will translate 16-bit AXI transfers into two
    8-bit FMC transfers, which allows the 8-bit LCD bus to
    work with DMA2D. The NWAIT pin does need to be "wasted"
    on a fixed 3v3 input, since the FMC expects to poll it
    (normally it would be the busy signal from a NAND chip).
    It's seems likely this can be disabled by clearing the
    PWAITEN bit so I've added a solder jumper to test it.
    This saves 7 pins off the LCD data bus. The IM pins are
    now fixed which saves another 2 pins.
    [echo-r1.kicad_sch, pins_stm32h7r3z8j6.ods]
2025-06-11 R1-Rev2: update LDO power supplies for codec and RTC
    The codec analog supplies (AVDD/DRVDD) are now fed through
    a 3.0V LDO powered off the main 3.3V buck regulator, which
    improves worst case efficiency from ~78% to around 86% and
    avoids stability issues that might occur when the battery
    gets within the dropout voltage range.
    The new LDO (AP2125) has a very low dropout at loads well
    above what the codec draws, so it should function perfectly
    even at low battery levels. In theory, everything except
    the memory card should still function almost all the way
    down to 3.0V.
    A second LDO powered from the battery is still needed just
    for the RTC, but that's not too big a deal.
    [adc_calcs.ods, echo-r1.kicad_sch, power_supply.kicad_sch]
2025-06-11 R1-Rev2: fix backlight PWM connectivity
    Connect PWM to the backlight driver MOSFET and remove
    the unneeded backlight_pwr_en signal to free up a pin.
    [echo-r1.kicad_sch, pins_stm32h7r3z8j6.ods]
2025-06-11 R1-Rev2: change LCD ribbon cable slot placement and size
    The LCD won't sit flat if the fat side of the cable is lying
    underneath it because there are a bunch of capacitors there.
    The cable is long enough to reach the back of the PCB though
    if the entire thing is put through a slot right underneath
    the screen, although it's annoyingly huge.
    I've removed the screw holes there since the routing becomes
    very tight in that area with them in place. Depending on how
    it goes there might be room to bring one of them back or put
    a screw in the middle, between the slot and the D-pad.
    [echo-r1.kicad_pcb, echo-r1.kicad_sch]
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2025-06-11 R1-Rev2: updates to PCB layout, add HyperRAM routing
    - Reannotate schematic and assign footprints for passives
    - First try at HyperRAM routing
    - Fixed incorrect W958D8NBYA5I pinout
    [audio.kicad_sch, echo-r1.kicad_pcb, echo-r1.kicad_sch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]
2025-06-11 R1-Rev2: update USB D+/D- net ties to avoid USBHS stubs
    The USB data lines have to be routed to both HS and FS PHYs
    since only the FS PHY supports DFU mode. To minimize stub
    length in HS operation, the data lines from the connector
    should route through the FS pins first and terminate at the
    HS pins.
    [echo-r1.kicad_pcb, echo-r1.kicad_sch]
2025-06-11 R1-Rev2: add inductor footprint and group components
    Also use the same 2.2uH inductor for the buck converters,
    to minimize unique component count.
    [echo-r1.kicad_pcb, echo-r1.kicad_sch, power_supply.kicad_sch]
2025-06-11 R1-Rev2: improve reset circuit, add XSPI CS pullup
    Connect NRST to xspi_reset and the regulator power-good signals.
    This should ensure that the STM32 and RAM will stay in reset
    until both power rails have started up. It shouldn't be necessary
    to control xspi_reset with a GPIO, but for now leave it connected
    just in case.
    The XSPI CS pin also requires an external pullup to guarantee it
    will be pulled high during power-on, which is required to ensure
    the RAM resets properly.
    [audio.kicad_sch, echo-r1.kicad_pcb, echo-r1.kicad_sch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]
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2025-06-11 R1-Rev2: move LCD in Z-axis to free up board space
    Mounting the LCD directly to the PCB just proved to be too
    awkward; mainly because the connector position made it hard
    to fit components on the upper half of the PCB. Mounting it
    on top of a 1.2mm support which directly contacts the PCB
    alleviates this, and the cable slot can now be smaller and
    moved up closer to the connector. This provides a bit more
    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
    [echo-r1.kicad_pcb, echo-r1.kicad_sch]
2025-06-11 R1-Rev2: update pin assignment; add internal memory card slot
    - Removed old H743 and H7R3 LQFP144 pin assignment sheets
    - Updated pin assignments to make room for a 2nd card slot
    - Added internal memory card slot
    - Unassigned GPIOs and removed WIP routing
    - Fixed net tie reference designators
    [audio.kicad_sch, echo-r1.kicad_pcb, echo-r1.kicad_sch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]
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2025-06-11 R1-Rev2: use LDO enable pin to control codec AVDD supply
    Now that the codec has a dedicated power supply for AVDD,
    the LDO's enable pin can be used for power sequencing.
    This eliminates a resistor and PMOS.
    [audio.kicad_sch, echo-r1.kicad_pcb, echo-r1.kicad_sch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]
2025-06-11 R1-Rev2: place battery connector and fix footprint courtyard
    [echo-r1.kicad_pcb]
2025-06-11 R1-Rev2: combine SWD/UART connectors into a single 1x7 header
    [echo-r1.kicad_pcb, echo-r1.kicad_sch]
2025-06-11 R1-Rev2: add optional connection point for a wired battery
    [echo-r1.kicad_pcb, echo-r1.kicad_sch, power_supply.kicad_sch]
2025-06-11 R1-Rev2: fix/improve fab layer text on a few footprints
    [echo-r1.kicad_pcb, power_supply.kicad_sch]
2025-06-11 R1-Rev2: add netclasses for easier visibility when routing
    [echo-r1.kicad_pcb]
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2025-07-29 R1-Rev2: fix courtyards on LCD connector and TVS diodes
    [echo-r1.kicad_pcb]
2025-07-29 R1-Rev2: remove stray documentation files
    These are inapplicable and some should have been removed, but
    accidentally got revived when restructuring the repo.
    [bom.ods, pins_stm32h7r3z8j6.ods, pins_stm32h7r3z8t6.ods]
2025-09-02 R1-Rev2: move lcd.dcx pin to FMC_A19
    DMA2D always auto-increments the destination address, unlike
    normal DMA which has the option not to. The LCD is mapped as
    an 8-bit memory and DMA2D will perform 16-bit transfers so
    the number of pixels transferred must be <= 2**x / 2 if FMC_Ax
    is the DCX pin; otherwise the transfer will end up toggling
    DCX and won't operate correctly.
    Since 320*240 pixels exceeds the limit if FMC_A16 is used as
    the DCX pin, move DCX to a higher FMC address pin.
    [echo-r1.kicad_sch, pin_assign.ods]
2026-02-12 Rename R1-Rev1 -> R1-Rev1.1
    The "Rev1" in-tree is really a new board revision distinct
    from the true Rev1 board that got manufactured. Rename the
    in-tree "Rev1" to Rev1.1. This makes it less confusing to
    talk about different board revisions and will make it easy
    to keep the original Rev1 schematic in tree for reference
    (and provide a sensible place to document errata for it).
    [Echo-R1-Rev1.FCStd, audio.kicad_sch, bom.ods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]
2026-02-12 Restore original Rev1 schematic and PCB
    This is the first version of the hardware from before the
    Rev1.1 modifications. Has been updated to use the shared
    symbol/footprint library and stuff from the KiCAD library
    has been updated (eg. PMOS symbols renamed, and the STM32
    symbol received cosmetic changes) so it is not an exact
    match of the initial commit but the PCB layout should be
    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
    [audio.kicad_sch, bom.ods, buttons.kicad_sch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]
2026-02-12 Update schematic comments for Rev1 & Rev1.1
    Mark Rev1 as released & not recommended for manufacture.
    Update revision number for Rev1.1 and mark it as under
    development.
    [audio.kicad_sch, buttons.kicad_sch, cpu_memory.kicad_sch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]
2026-02-13 Add revision suffix to KiCAD project filenames
    Makes it easier to see which version you have open.
    [audio.kicad_sch, buttons.kicad_sch, cpu_memory.kicad_sch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]
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2026-02-15 R1-Rev1: case: fix battery thickness and increase battery box depth
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2026-02-15 R1-Rev1: case: replace back plate columns with side-facing screw holes
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2026-02-15 R1-Rev1: case: fix outer side wall thickness
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2026-02-15 R1-Rev1: case: fix battery terminals not aligned with connector
2026-02-15 R1-Rev1: pcb: fix battery positon on fab layer
    [echo-r1-rev1.kicad_pcb]
2026-02-15 R1-Rev1.1: pcb: fix battery position on fab layer
    [echo-r1-rev1.1.kicad_pcb]
2026-02-15 R1-Rev1: case: increase case depth to fix a couple issues
    1. Increases the thickness of the back plate around the battery;
    2. Prevents raised shadow line from hitting the LO capacitors.
2026-02-15 R1-Rev1: case: reinforce back plate squares to reduce deformation
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2026-02-15 R1-Rev1: case: increase clearance on side buttons
2026-02-15 R1-Rev1: case: slight adjustments to battery frame
    Increase wall depth and add extra clearance for connector
    pins to make assembly easier. Remove the walls around one
    of the support screws because they don't serve any real
    purpose; and this allows fitting screws with a wider head
    than a standard M2 screw.
2026-02-15 R1-Rev1: case: increase clearance of side buttons from PCB surface
    This finally gets them to work properly although they are a
    bit difficult to print.
2026-02-15 R1-Rev1: case: make lower shell corner squares a uniform 2.5mm thickness
    The thicker plastic doesn't really help much and one of them
    is impinging on the card connector.
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2026-02-15 R1-Rev1: case: fix clearance on battery box
    Reduce clearance around battery to ensure battery fits
    snugly and prevent losing contact.
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2026-02-15 R1-Rev1: case: improve side button geometry
    Simplify the button geometry; add supports to close up
    the gap between the wall and PCB to reduce jamming.
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2026-02-15 R1-Rev1: case: add clearance between volume pivot screw and battery
2026-02-15 R1-Rev1: case: increase battery frame wall height
    Hopefully will counteract the tendency of the battery
    to pop loose when removing the back plate.
2026-02-15 R1-Rev1: case: reinforce volume support on battery frame
2026-02-15 R1-Rev1: case: fix hole for d-pad pivot screw in battery frame
2026-03-22 Remove BOM spreadsheets
    The BOM generation script works with part numbers extracted from
    the KiCAD schematic. This makes a separate manually maintained BOM
    spreadsheet unnecessary.
    [bom.ods]
2026-03-22 Fix USB3320C ID pin
    The ID pin should be tied to VDD33 or left floating for
    device mode. Tying to ground puts the PHY into host mode,
    which requires a software workaround to get USB working.
    See Github issue: #9
    [echo-r1-rev1.1.kicad_pcb, usb.kicad_sch]
2026-03-22 Fix symbol library links & resync footprints from KiCAD libraries
    [audio.kicad_sch, echo-r1-rev1.1.kicad_pcb, echo-r1-rev2.kicad_pcb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]
2026-03-22 Fix incorrect 3.5mm jack pinout
    Document the R1-Rev1's wrong pinout properly and fix the pinout
    in later revs so that jacks will work properly without needing
    a custom adapter.
    See Github issue: #12
    [audio.kicad_sch, echo-r1-rev1.1.kicad_pcb, echo-r1-rev1.kicad_pcb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]
2026-03-22 R1-Rev1: document errata for SDMMC bus ESD diodes
    ESD diodes on the SDMMC bus have too high a capacitance and
    cause errors particularly during high-speed operation (50MHz).
    Mark as DNP on the schematic.
    See Github issue: #27
    [echo-r1-rev1.kicad_pcb, sdcard.kicad_sch]
2026-03-22 R1-Rev1.1: remove SDMMC ESD diodes and adjust routing
    Remove the CESD3V3-AP ESD diodes and put a TODO to select
    new diodes later. While here, reroute the SDMMC bus a bit
    so it's not so messy.
    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
    [echo-r1-rev1.1.kicad_pcb, sdcard.kicad_sch]
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
